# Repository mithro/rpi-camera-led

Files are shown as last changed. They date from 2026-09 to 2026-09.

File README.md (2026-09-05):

# RPi Camera LED

An interposer for the Raspberry Pi camera flex cable (15 pin, 1.0 mm pitch FPC).
It sits in the middle of the cable, passes all fifteen camera signals straight
through, and adds a CH32V003A4M6 that gives the Pi I2C-controlled camera GPIO,
PWM illumination LEDs and an ambient light reading.

## Hardware

[KiCad schematic](hardware/rpi-camera-led.kicad_sch) ·
[PDF](hardware/rpi-camera-led.pdf) ·
[board](hardware/rpi-camera-led.kicad_pcb)

### Board: 15-way FFC camera interposer

| 3D render, top | 3D render, bottom | Layout (copper, silk, outline) |
|:---:|:---:|:---:|
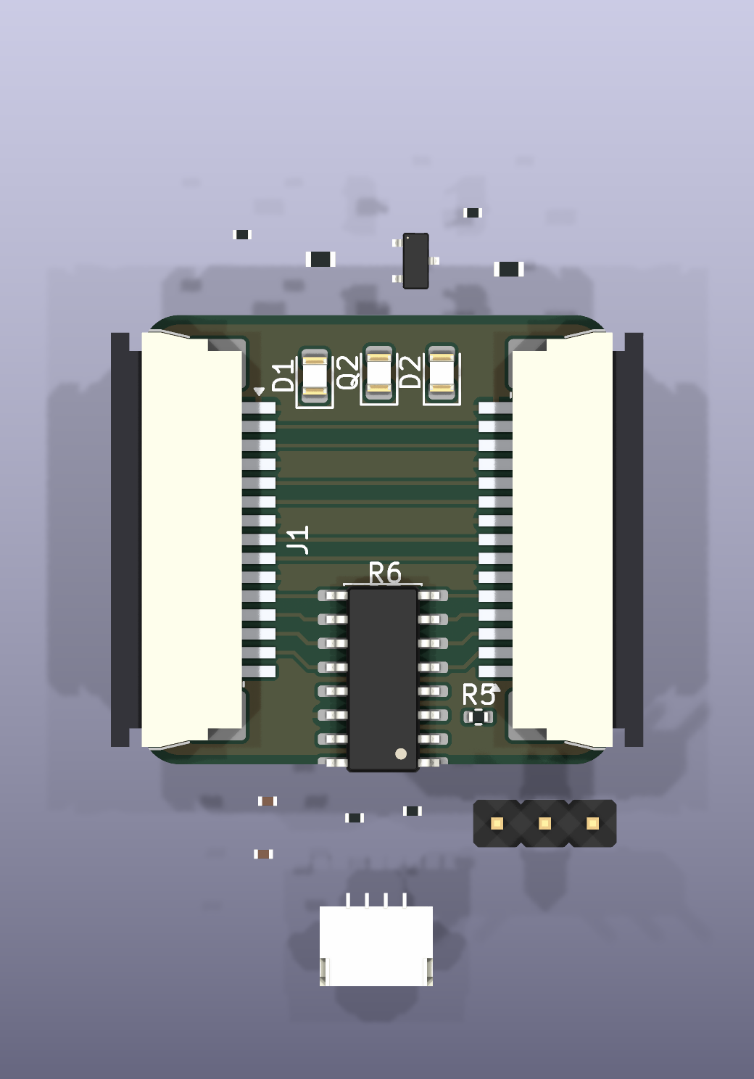
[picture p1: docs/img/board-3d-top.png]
Interposer, front side
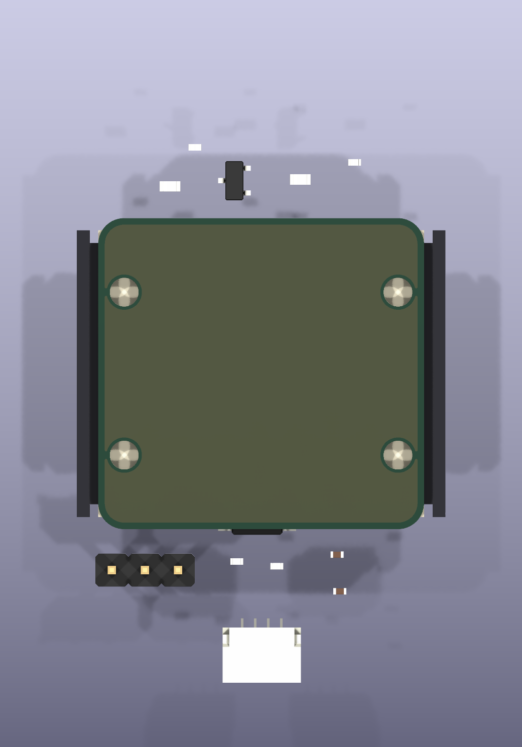
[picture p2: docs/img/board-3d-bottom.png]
Interposer, back side
|  |  | Interposer copper layout |

25.0 × 23.9 mm, two layers, everything on the front. J1 (left) faces the
Raspberry Pi and J2 (right) faces the camera; they sit 180° apart so the two
cable segments leave opposite edges and the board drops into an existing cable
run in line. The MCU is the SOIC-16 in the middle, the two white illumination
LEDs and the phototransistor are along the top edge.

The outline is the Camera Module 2 board: 25.000 × 23.862 mm with 2.0 mm corner
radii, and the same four Ø2.2 mm mounting holes, so the interposer takes the
camera's screws. Those come straight off the official mechanical drawing
([RP-008149-DS](https://pip.raspberrypi.com/categories/1205-drawings-and-schematics),
RPI-CAM-V2_1): *"4x 2.2mm diameter holes"*, 2 mm in from each end of the 25 mm
axis — a 21.0 mm pitch — and 12.5 mm apart on the other. `check_pcb.py` now
verifies pitch and drill, because these went missing once already without
anyone noticing.

**The layout is in progress.** Eleven of the twenty footprints — C1, C2, J3,
J4, Q1, R1–R4, R8 and R9 — are still parked outside the board outline, which is
why they float around the board in the renders. The fifteen-way pass-through
bus is routed; the rest is not. DRC reports 21 violations and 34 unconnected
items.

Four of those violations are the mounting holes, and they are a real conflict
rather than noise. **All four holes land underneath a connector housing.** On
the camera the 21.0 mm pitch runs between two edges that carry nothing, and its
single FFC connector sits on a third; this board has a connector on *both* ends
of that axis, each housing 5.30 mm deep, so the holes — 2 mm in from each end —
sit under them. Nothing on the board is wrong in isolation; the camera's
mounting pattern and two edge-mounted connectors simply cannot both fit on a
25 mm span. Resolving it means giving something up: a longer board, connectors
on the 25 mm edges instead, or mounting holes that no longer match the camera.

### How the cables run

| With cables fitted | Isometric |
|:---:|:---:|
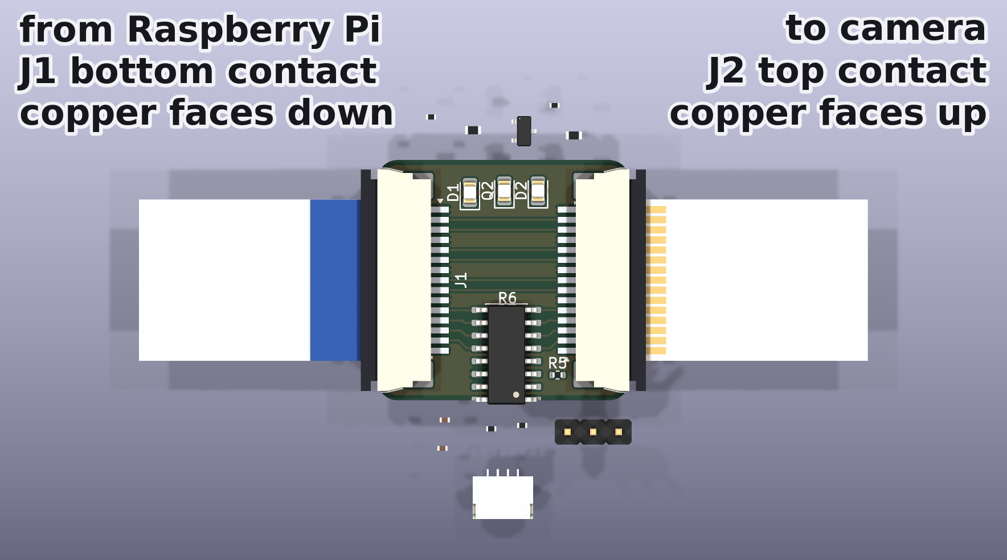
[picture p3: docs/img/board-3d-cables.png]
Interposer with FFC cables in both connectors
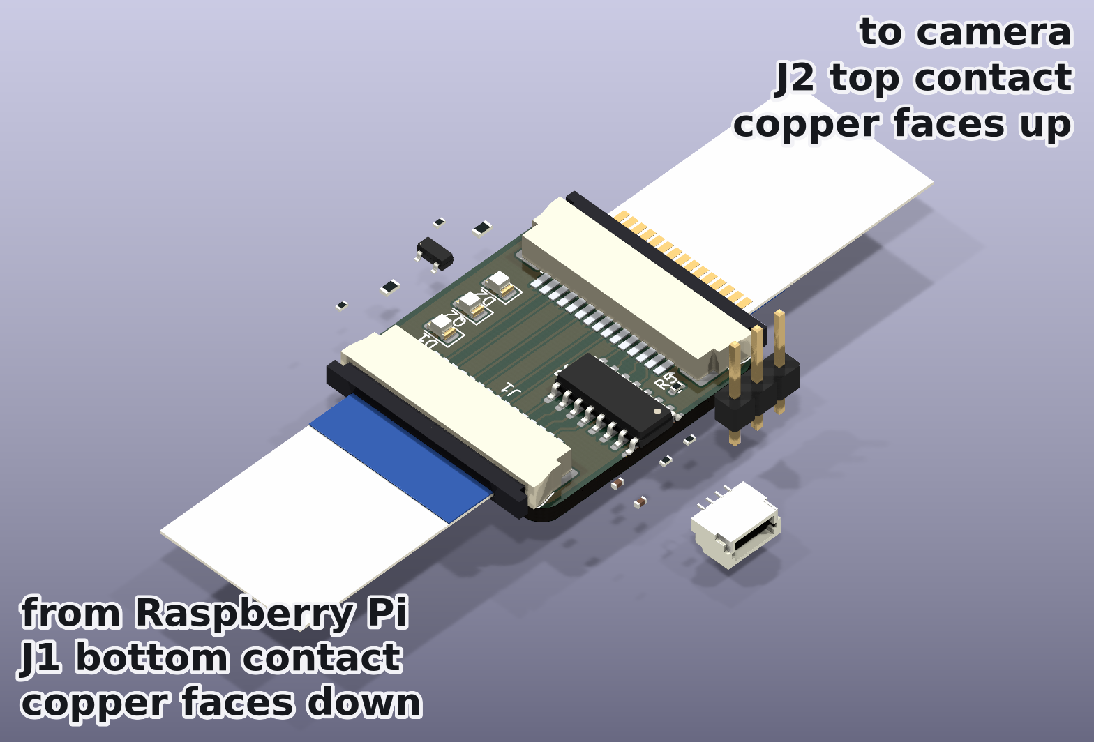
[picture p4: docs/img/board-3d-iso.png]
Isometric view of the interposer with cables
|  |  |

Both cables enter from the **outside** edges and run away from the board in
opposite directions, so the interposer drops into an existing cable run in
line. That follows from where the cable entry is on this connector: the
manufacturer's Section A‑A shows the solder tail stepping down and out at one
end while the cable channel opens at the other, and the top view labels
*Terminal* at one end and *Latch* at the other with the 5.30 mm housing
between them. It is also the only way a slide lock can work — you pull the
slider, insert the cable and push it back, all at the same end. So the cable
entry is at the latch end, away from the pads, and with each connector's
housing flush against its board edge that entry points outward.

The two cable stubs are drawn different ways up, and that is the point. J1 is
bottom contact, so its cable presents bared copper *downwards* and shows you
the blue backing; J2 is top contact, so its cable is the other way up and
shows you the conductors. That flip is the whole reason for pairing an F part
with an E part, and it is what lets both segments be ordinary Raspberry Pi
camera cables — the same flip you can see in a real cable, blue stiffener on
one face at one end, bared conductors on the other face at the other.

The stubs are illustrative and are not part of the board: they exist only in a
throwaway copy that the render script builds and deletes. Their 16.00 × 0.30 mm
section is the drawing's recommended FFC dimension. The bared conductors and
the backing are drawn a little longer than the 4 mm insertion depth so that a
few millimetres of each stay visible outside the connector — otherwise the
orientation they exist to show would be buried inside it.

Regenerate the images with `uv run hardware/tools/render_board.py`, and the
connector models with `uv run hardware/tools/gen_connector_model.py`. The
render script refills the copper zones first, via the pcbnew Python module
inside the KiCad snap, because `kicad-cli` has no zone-fill command and a
stale pour renders as authoritatively as a fresh one — when this was first
wired up the stored B.Cu pour was less than half its true area, and refilling
it dropped DRC from 116 violations to 17.

### Connectors, and which cables fit

J1 and J2 are **not** the same part, and that is deliberate:

| | part | contacts | mates with |
|---|---|---|---|
| **J1** → Raspberry Pi | JUSHUO AFA07-S15**F**CA-00 (LCSC C262721) | **bottom** — cable copper faces the board | a standard Pi camera cable |
| **J2** → camera | JUSHUO AFA07-S15**E**CA-00 (LCSC C262742) | **top** — cable copper faces away | a standard Pi camera cable |

The reason is cable parity. A Raspberry Pi camera cable is an *opposite-side*
FFC — "type 2", contacts on one face at one end and the other face at the other
— because the Pi's CSI socket is top-contact and the camera module's is
bottom-contact. Cutting one continuous cable anywhere yields one same-side half
and one opposite-side half, so an interposer whose two connectors want the
copper on the *same* face forces one odd, hard-to-buy cable. One that wants it
on *opposite* faces absorbs the asymmetry, and both segments become ordinary
Raspberry Pi camera cables. Bottom-contact at J1 plus top-contact at J2 is that
pairing.

The two variants share one land pattern — verified against both JUSHUO drawings
— so nothing on the board moves between them. Since only the contact side
differs, and it is invisible on an assembled board, the distinction is called
out in each symbol's value, in the MPN, and as a `BOTTOM CONTACT` / `TOP
CONTACT` marker on the fab layer.

Both footprints and their 3D models live in this repository, in
`hardware/rpi-camera-led.pretty` and `hardware/rpi-camera-led.3dshapes`. KiCad's
stock footprint references a STEP file for the JUSHUO AFA07 series that does not
exist — not in the KiCad distribution and not in `kicad-packages3D` upstream,
which ships no JUSHUO models at all. Third-party libraries have one, but under
terms that forbid redistribution, so `hardware/tools/gen_connector_model.py`
builds it from the manufacturer's published drawing instead: a 22.00 × 6.95 ×
2.50 mm envelope matching the drawing's DIM D, the F.Fab outline and the side
view's height, with the housing and latch coloured as the drawing's notes
specify. Both STEP and WRL are generated, the latter in the 0.1-inch units
KiCad expects.

The pass-through bus is wired J1 pin *k* ↔ J2 pin *16−k*. That looks reversed
but is exactly right: the two connectors are 180° apart, so J1 pad *k*
physically faces J2 pad *16−k*, and joining the pads that face each other is
both the straight route and the electrically transparent one — the board
behaves as a splice in the middle of one continuous cable.
`check_pcb.py` measures that facing alignment as a number, because losing it to
a stray drag puts a dogleg in all fifteen nets and is invisible by eye.

### Verifying

```
uv run hardware/tools/check_schematic.py   # ERC + netlist vs design intent
uv run hardware/tools/check_pcb.py         # connector alignment + DRC parity
```

`check_schematic.py` currently **fails**: its expected-netlist table still
describes the older pin-for-pin bus, and four issues from the last eeschema
session are open — U1 pin 13 is unconnected, SWIO and CAM_IO1 have been merged
onto one net, I2C is landed on pins that cannot carry it on this package (the
CH32V003 SOP-16 reaches the peripheral only on pins 1 and 2, since both AFIO
remaps need PD0 or PC5 and the package bonds out neither), and four no-connect
flags dangle.

The schematic is maintained by hand in eeschema — connections between adjacent
parts are drawn as wires rather than left implicit in matching global labels.
`hardware/tools/gen_schematic.py` is the generator that bootstrapped it, but
**running it overwrites the schematic** and would discard that manual wiring.

## Firmware

[CH32V003 firmware](firmware/README.md): a fail-safe I2C bootloader plus an
application exposing camera GPIO control, RPi-side GPIO readback, GPIO
pass-through, LED brightness (hardware PWM) and an ambient light reading over
a Linux-friendly SMBus register map at address 0x42. Builds with
`riscv64-unknown-elf-gcc` and [ch32v003fun](https://github.com/cnlohr/ch32v003fun)
(`git submodule update --init`, then `make` in `firmware/bootloader` and
`firmware/app`).

The firmware still targets the older pin map and needs updating to match the
current schematic.

## Research

Part availability research comparing [JLCPCB's PCBA parts
library](https://jlcpcb.com/parts) and [NextPCB's Rev0
service](https://www.nextpcb.com/rev0-pcba) (which sources components from [HQ
Online](https://www.hqonline.com/)'s 600k+ in-stock inventory):

* [I2C controllable RGB LEDs](research/i2c-rgb-leds.md)
* [I2C GPIO expanders with LED driving capability](research/i2c-gpio-expanders.md)
* [Cheap (< $0.50) MCUs with I2C and no external parts required](research/cheap-mcus.md)
* [RPi camera compatible FPC connectors (1.0 mm pitch, 15 pin)](research/fpc-connectors.md)

## License

Apache 2.0 — see [LICENSE](LICENSE).

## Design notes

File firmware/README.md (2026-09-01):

# CH32V003J4M6 camera-LED controller firmware

Firmware for the CH32V003J4M6 (RISC-V, SOP-8) sitting on the Raspberry
Pi camera interposer board in this repository. It:

1. drives or tri-states the two camera-side GPIO pins,
2. reads back the two Pi-side GPIO pins (via the tri-stated passthrough),
3. can put either channel into "copy mode" (the Pi's GPIO passes
   straight through to the camera),
4. continuously samples and averages an ambient-light phototransistor,
5. drives two white illumination LEDs via hardware PWM, and
6. supports a fail-safe firmware upgrade over I2C.

Everything is controlled by a Raspberry Pi over I2C, using a plain
"8-bit register pointer, auto-incrementing" protocol compatible with
`i2c-tools` (`i2cget`/`i2cset`/`i2ctransfer`) and kernel `regmap-i2c`
drivers out of the box.

**Build status: builds clean with fully open-source tooling (see
"Build" below). Hardware status: UNTESTED. Nobody has flashed this
onto a real board or scoped a single pin -- see "Known risks" and
"What is untested" at the end of this document.**

## Hardware

(As specified by the person who wrote this brief, verified against the
WCH datasheet.) The chip is a CH32V003J4M6 in an SOP-8 package. Several
package pins are bonded to two GPIO ports simultaneously inside the
package, which the firmware must account for:

| Package pin | Port(s) | Net | Notes |
|---|---|---|---|
| 1 | PD6 **and** PA1  | CAM_IO0 | Drives camera GPIO 11. Also wired through a 10k (R6) to the Pi's CAM_IO0: when the CH32 pin is an input, the Pi's state passes through to the camera and is readable by the CH32; when the CH32 drives it, it overrides the Pi (0.33mA through the 10k). |
| 3 | PA2 | CAM_IO1 | Same scheme via R7 (10k) to the Pi's CAM_IO1. |
| 5 | PC1 | I2C1_SDA  | CH32 is an I2C **slave** on the Pi camera bus (100-400kHz), shared with the camera sensor (0x10/0x1A/0x36) and EEPROMs (0x50/0x54). |
| 6 | PC2 | I2C1_SCL  | |
| 7 | PC4 | ADC A2 | Phototransistor, 47k to GND; more light = higher voltage. |
| 8 | PD1, PD4, PD5 | LED gate  | PD1 drives an N-MOSFET gate (100R series, 10k pulldown) switching two white LEDs, via TIM1 channel 3 complementary output (T1CH3N). PD1/SWIO is also the programming pin -- LEDs flicker during flashing, by design. |

Because pins 1 and 8 are bonded to more than one port, the firmware
configures the *unused* half of each bonded pin as a floating input
for its entire lifetime, so it never fights the pin it's bonded to:
PA1 (pin 1) and PD4/PD5 (pin 8) are always `GPIO_CFGLR_IN_FLOAT`. This
is also the chip's power-on-reset default for every GPIO, so the
bootloader (which never touches these pins) is safe by construction,
and the app explicitly re-asserts it at startup as a defensive measure
(`app/app.c`, `main()`).

I2C slave address: **0x42** (`I2C_SLAVE_ADDR` in `common/layout.h`),
chosen to avoid the camera (0x10/0x1A/0x36) and EEPROMs (0x50/0x54)
already on the bus.

## Architecture

16KiB of flash is split into two independently-linked images:

```
0x0000 - 0x0FFF   bootloader   (4KiB)   -- always runs first
0x1000 - 0x3FFF   application  (12KiB)  -- code + a 16-byte trailer
```

2KiB of SRAM is shared: the first 16 bytes are reserved for a
cross-reset handshake word (see "Upgrade protocol" below) that is
**not** zeroed by C runtime startup, so it can carry a value across a
warm reset; the rest is split identically by both linker scripts
(`bootloader/bootloader.ld`, `app/app.ld`) but is otherwise fully
available to whichever image is currently running -- the two images
are never active at the same time, so there's no need to partition RAM
between them beyond that one shared word.

The bootloader **always** runs first (the chip always starts executing
at flash address 0 after reset). On every boot it:

1. Computes the application's CRC32 and compares it to the CRC32
   stored in the application's own trailer.
2. If valid **and** no upgrade was requested, jumps straight to the
   application. This is not free: the CRC32 is bit-banged (see
   `common/crc32.h`, deliberately table-free to save flash) at roughly
   70 CPU cycles per byte, so 12KiB costs on the order of **20ms** at
   48MHz. The device does not acknowledge anything on I2C during that
   window, on every reset and every power-on. That is comfortably
   inside the time a Raspberry Pi takes to get as far as probing the
   camera bus, but it is worth knowing about, and it is the price of
   the guarantee in point 1.
3. Otherwise, stays resident and serves the I2C bootloader protocol
   until a host either fixes the app and asks it to run, or the app
   itself explicitly asks to be interrupted for an upgrade.

The bootloader **never** erases or programs any flash address outside
the 12KiB application region -- see `program_page()` in
`bootloader/bootloader.c`, which bounds-checks every page index
against `APP_NUM_PAGES` before touching the flash controller. There is
no code path, valid or malformed I2C command, that can make it write
to its own 4KiB.

### Why two separately-linked images "just work"

Each image is built by ch32fun's normal startup code (`handle_reset`
in the submodule's `ch32fun.c`), which sets `mtvec` to that image's
*own* `InterruptVector` symbol (`la a3, InterruptVector; ori a3,a3,3;
csrw mtvec,a3`) and jumps into that image's own `main()`. Since the
bootloader and app are linked with different `FLASH` origins
(`bootloader.ld`: `0x00000000`; `app.ld`: `0x00001000`), this happens
automatically -- the bootloader does not need to (and does not)
manually relocate the app's vector table. "Jumping to the app" is
therefore just a plain function-pointer call to `APP_FLASH_BASE`
(`0x00001000`), which lands on the app's own reset vector and the app
takes it from there (`jump_to_app()` in `bootloader.c`).

Flash reads/writes/erases use the *physical* address
(`APP_FLASH_PHYS_BASE = 0x08001000`), matching how
`ch32v003fun/examples/flashtest/flashtest.c` uses the flash controller
-- the CPU's normal code-fetch/read path uses the *aliased* address
(`APP_FLASH_BASE = 0x00001000`, the boot-remapped alias flash sits at
after reset) for execution. Both addresses read the same bytes; only
the *jump* target needs to be the aliased one (to match what `mtvec`/
`la` compute), and only the flash-controller `FLASH->ADDR`/buffer
writes need to be the physical one (as demonstrated by the stock
`flashtest.c` example).

## Register map (application mode)

I2C slave address `0x42`. All registers are 8-bit-addressed with
auto-increment (a write's first byte sets the pointer; further bytes
in the same write auto-increment it; a read serves from the pointer
and also auto-increments) -- see `common/i2c_slave.h` (MIT-licensed,
vendored from the ch32v003fun submodule's `examples/i2c_slave` **with
local bug fixes**, listed in the header comment of that file). This is
the same "dumb register file" shape `i2c-tools` and kernel
`regmap-i2c` drivers expect.

Both a combined write-then-read (repeated START -- what `regmap-i2c`,
`i2cget -c` and the `I2C_RDWR` ioctl issue) and a separate
write-then-STOP-then-read work: the register pointer is remembered
across transactions, and each addressing phase restarts the burst from
it. The pointer is *not* advanced by a completed read, so repeating a
read without rewriting the pointer re-reads the same registers.

Registers marked RO are re-stamped by the firmware from private state.
The underlying slave driver has one read-only flag for the entire
register file, and the file has to be writable for the RW registers,
so a host physically *can* write to an RO offset -- but the firmware
never believes what it finds there and restores it.

| Reg  | Name | R/W | Description |
|---|---|-----|---|
| 0x00 | WHO_AM_I | RO  | `0xC3` in application mode, `0xB1` in bootloader mode -- read this first to know which one you're talking to. |
| 0x01 | FW_VERSION | RO  | Application firmware version (currently 1). |
| 0x02 | CTRL | RW  | bit0/bit1 = copy-mode enable, channel 0/1. |
| 0x03 | GPIO_OUT | RW  | bit0/bit1 = driven output level, channel 0/1 (only takes effect if OE=1 and copy-mode is off for that channel). |
| 0x04 | GPIO_OE | RW  | bit0/bit1 = 1: drive the pin per GPIO_OUT, 0: tri-state (input). Ignored (forced to tri-state) while copy-mode is enabled for that channel. |
| 0x05 | GPIO_IN | RO  | bit0/bit1 = live pin level, channel 0/1. When tri-stated (copy mode, or OE=0) this is the Pi's passed-through state; when driven (OE=1, copy mode off) this reads back the value we're driving. |
| 0x06 | LED | RW  | LED brightness, 0-255, hardware PWM (~1kHz). 0 is fully off (0% duty), 255 is fully on (100%, not 255/256). |
| 0x07 | (reserved) | - | Reads as 0. |
| 0x08-0x09 | LIGHT | RO  | Illumination, little-endian 16-bit, exponentially averaged (8-sample time constant at 100Hz sampling). Raw ADC is 10-bit, so the value ranges 0-1023, not the full 16-bit range. The two bytes are updated with interrupts masked, so a single 2-byte burst read always returns one consistent sample. |
| 0x7F | BOOT | WO  | Write `0xB0` to ask the running app to reset into the bootloader for a firmware upgrade. |

**Copy mode precedence:** if `CTRL` bit *n* is set, channel *n* is
**always** tri-stated regardless of `GPIO_OE` bit *n* -- that tri-state
*is* the passthrough (the Pi's own driver, through the 10k resistor,
is what reaches the camera; the CH32 just gets out of the way and
reports what it reads back on `GPIO_IN`).

## Register map (bootloader mode)

Same I2C address (`0x42`) and same register-pointer/auto-increment
protocol, exposed only while the bootloader is resident. `WHO_AM_I`
reads `0xB1` here (vs `0xC3` in app mode) so a host can always tell
which firmware it's talking to just by reading register 0.

| Reg | Name | R/W | Description |
|---|---|-----|---|
| 0x00 | WHO_AM_I | RO  | `0xB1`. |
| 0x01 | BL_VERSION | RO  | Bootloader version (currently 1). |
| 0x02 | STATUS | RO  | bit0 BUSY, bit1 OK (last op), bit2 ERR (last op), bit3 APP_VALID (result of the most recent CRC32 check). Informational only -- `RUN_APP` re-verifies from flash and does **not** consult this bit. |
| 0x03 | CMD | WO  | Write a command byte: `0x01` PROGRAM_PAGE, `0x02` VERIFY_APP, `0x03` RUN_APP. BUSY is raised in the same interrupt that accepts the write, so a host may poll STATUS immediately afterwards without racing the command's start. |
| 0x04 | PAGE_INDEX | RW  | Page number (0-191) within the 12KiB application region, for the next PROGRAM_PAGE. |
| 0x05-0x06 | PAGE_CSUM | RW  | Little-endian CRC16/CCITT-FALSE of the 64-byte PAGE_BUF, checked by the bootloader before it touches flash. |
| 0x07 | (reserved) | - | Reads as 0. |
| 0x08-0x47 | PAGE_BUF | RW  | 64-byte page data buffer (the CH32V003's flash erase granularity). |
| 0x48-0x4B | APP_CRC32 | RO  | Little-endian, the CRC32 computed by the most recent VERIFY_APP (or the automatic check at bootloader entry). |
| 0x4C-0x4F | APP_SIZE | RO  | Little-endian, `app_header_t.app_used_size` as last read from flash (always 12288 for images built by this repo's tooling). |

### `PROGRAM_PAGE` semantics

Writing `0x01` to `CMD` erases, programs, and read-back-verifies
*exactly one* 64-byte page of the application region at `PAGE_INDEX`,
from `PAGE_BUF`, but **only if** the CRC16 the bootloader computes over
`PAGE_BUF` matches `PAGE_CSUM` -- a mismatch aborts before touching
flash and sets the ERR bit. This work happens in the bootloader's main
loop (not the I2C interrupt handler), so it can take a few
milliseconds (flash page erase is documented elsewhere in the
ch32v003fun project as ~3ms); **a host must poll STATUS until BUSY
clears (or simply wait ~10ms) before sending the next command** --
see `_wait_not_busy()` / `_program_page()` in `host/rpi_camera_led.py`.
`PAGE_INDEX` is always bounds-checked against the 192-page application
region before any flash access, so a confused or malicious host cannot
make the bootloader touch its own 4KiB.

## Upgrade protocol and its fail-safety argument

The application's flash image ends in a 16-byte trailer
(`app_header_t`, `common/app_header.h`) occupying exactly the last 16
bytes of the last (192nd) page of the application region:

```c
typedef struct {
    uint32_t magic;          // must equal 0xCAFEB007
    uint32_t app_used_size;  // bytes covered by crc32 below, from the
                              // start of the app region (always 12288
                              // for images this repo's tooling builds)
    uint32_t app_crc32;      // CRC32 (zlib/CRC-32/ISO-HDLC variant) of
                              // app_used_size bytes, computed with THIS
                              // FIELD treated as zero
    uint32_t reserved;       // must be 0
} app_header_t;
```

Because the trailer sits at a fixed, compile-time-known address
(`APP_HEADER_ADDR = 0x00003FF0`) regardless of how big the actual
compiled code is, the bootloader never needs to trust anything about
the application's own build beyond this one fixed struct.

The full upgrade sequence, driven by `host/rpi_camera_led.py upgrade`:

1. If the device is currently running the app, write `0xB0` to
   `REG_BOOT`. The app stashes a magic value in the shared NOINIT RAM
   word and triggers a full system reset (`PFIC->SCTLR = 1<<31`). The
   bootloader (which always runs first) sees the magic value, clears
   it, and stays resident regardless of whether the current app's CRC32
   is valid.
2. For each of the 192 pages: write `PAGE_INDEX`/`PAGE_CSUM`/`PAGE_BUF`
   in one I2C transaction, then write `CMD = PROGRAM_PAGE` in a second,
   then poll `STATUS` until not-BUSY and check OK.
3. Write `CMD = VERIFY_APP`; poll; check `APP_VALID`.
4. Write `CMD = RUN_APP`; the bootloader jumps to the (now verified)
   app.

**Why a power cut at any point in this sequence is recoverable:**

- *Before any page is written*, the flash is whatever it was before --
  either the previous (working) app, or already-invalid flash from an
  earlier interrupted attempt. Either way, the CRC32 check at the next
  boot reflects reality.
- *During any single page's erase+program*, the flash controller
  (per `ch32v003fun/examples/flashtest`) can leave that specific page
  in an indeterminate state (partially erased, partially programmed)
  if power is cut mid-operation. This is **not** made atomic by this
  firmware -- it can't be, on this hardware, without a second flash
  bank to hold a journal, which a 16KiB part doesn't have. What *is*
  guaranteed is that the CRC32 check covers the **entire** 12KiB
  region, so **any** single corrupted page (this one, or the one
  holding the header trailer itself) makes the whole-image CRC32
  mismatch on the next boot, and the bootloader falls back to staying
  resident rather than running a partially-written image. The
  in-progress page write is bounds-checked to the app region the whole
  time, so even a power cut mid-erase can never touch the bootloader's
  own 4KiB.
- *Between pages*, or *after the last page but before VERIFY_APP/
  RUN_APP*, the trailer's CRC32 still describes whatever combination of
  old and new page contents happens to be in flash at that instant,
  which (overwhelmingly likely) does not match -- same fallback.
- *A power cut during RUN_APP itself* just means the reset happens
  before the jump instead of after; the bootloader re-runs its CRC32
  check from scratch on the next boot regardless.

There is also **no I2C command sequence that can make the bootloader
jump into an unverified image**. `RUN_APP` recomputes the CRC32 from
flash at the moment of the jump and ignores `BREG_STATUS`; the status
register is host-writable (see the note under "Register map
(application mode)"), so gating the jump on its `APP_VALID` bit would
have let a host write `[0x02, 0x08, 0x03]` -- STATUS = APP_VALID
followed by CMD = RUN_APP in one transaction -- and jump into a blank
or half-programmed app region. Likewise `app_used_size` read out of
the flash trailer is required to be exactly `APP_SIZE` before it is
used as a CRC length, because a corrupt smaller value would underflow
the length arithmetic into a multi-gigabyte walk past the end of flash
and hang the bootloader on every boot.

In short: **the fail-safety guarantee rests entirely on the CRC32
check being cheap, unconditional, and run on every single boot (and
again immediately before every jump) before anything else** -- not on
any single I2C transaction being atomic. The
cross-reset NOINIT handshake word (step 1 above) is *not* part of this
guarantee; it only affects whether the bootloader stays resident when
the CRC32 *is* valid (letting an intentional re-upgrade interrupt a
working app). Concretely: SRAM content after a genuine cold power-on
is not architecturally guaranteed to be any particular value, so this
firmware never relies on the handshake word being zero/absent after a
real power loss -- it only ever matters when the CRC32 is already
valid, and reading it as (spuriously) "enter bootloader" in that case
just means an extra unnecessary stay-in-bootloader, never an unsafe
boot into a bad image.

**What this cannot rule out, honestly:** CRC32 is not a cryptographic
checksum. A pathological, exactly-crafted flash corruption pattern
could in principle produce a wrong image whose CRC32 happens to match
its own (also corrupted) stored CRC32 field. Against the kind of
corruption that a power loss during a page erase/program actually
produces (a page left all-0xFF, all-0x00, or a mix of old/new 32-bit
words), this is not a realistic failure mode, but it is not
mathematically impossible, and this document says so plainly rather
than overclaiming.

The I2C-transport-level `PAGE_CSUM` (CRC16) is a **separate**, weaker
check that only protects a single page transfer against I2C bus
corruption *before* it reaches flash -- it plays no role in the
boot-time safety argument above, which is CRC32-only.

## Build

Requires `riscv64-unknown-elf-gcc` (Debian/Ubuntu package
`gcc-riscv64-unknown-elf`) and `uv` (for the trailer-patching Python
step). Both bootloader and app are built with
`-march=rv32ec -mabi=ilp32e`, matching what `ch32v003fun`'s own
`ch32fun.mk` selects for `TARGET_MCU=CH32V003`.

```sh
git submodule update --init firmware/ch32v003fun   # if not already checked out
cd firmware/bootloader && make build
cd ../app && make build
```

Each `Makefile` enforces its flash budget at build time (`checksize`
target) in addition to the linker's own `--print-memory-usage` report,
using `objcopy -O ihex`/`-O binary` for the standard `.elf`/`.bin`/
`.hex` outputs.

Measured sizes (this repository, current sources, gcc 14.2.0):

```
Bootloader:  2248 / 4096  bytes flash (54.9%),  144 / 2032 bytes RAM
App:         2020 / 12272 bytes flash (16.5%),  184 / 2032 bytes RAM
```

(App flash budget is 12272, not 12288 -- the linker script reserves
the last 16 bytes for the trailer that `app/make_trailer.py` patches
in after linking, so the *build itself* fails loudly if application
code would collide with the trailer, rather than silently producing a
corrupt image.)

## Flashing

This firmware has not been flashed to real hardware (see "What is
untested" below). `make flash` in either `bootloader/` or `app/` uses
`minichlink` (built from the `ch32v003fun` submodule, also fully
open-source) over a WCH-LinkE-compatible SWD programmer connected to
the shared SWIO/PD1 pin. Because PD1 is also the LED PWM pin, the LEDs
will flicker while flashing the app image -- this is expected and
harmless.

```sh
cd firmware/bootloader && make flash   # minichlink -w bootloader.bin flash        (0x08000000)
cd firmware/app        && make flash   # minichlink -w app.bin        flash+0x1000 (0x08001000)
```

**Do not use ch32fun.mk's own `cv_flash` target for the application.**
Its `FLASH_COMMAND` writes the image to the bare `flash` address, i.e.
the *start* of flash, which for this image would drop 12KiB of
application (linked to run at 0x1000) on top of the 4KiB bootloader.
`app/Makefile` therefore defines its own `flash` target at
`flash+0x1000`; it also depends on `build` rather than just `app.bin`,
so it cannot flash an image whose `app_header_t` trailer has not been
patched in yet.

The bootloader only needs to be flashed once (via SWD); subsequent
application updates go over I2C via `host/rpi_camera_led.py upgrade`,
which never touches the bootloader's own flash region.

## Host tool

`host/rpi_camera_led.py` (run with `uv run rpi_camera_led.py ...`,
stdlib-only, no packages to install) talks to `/dev/i2c-N` via a small
ctypes wrapper (`host/i2c_raw.py`) around the same `I2C_RDWR` ioctl
`i2c-tools`/`smbus2` use, so it does not depend on `smbus2` at all.

```sh
uv run host/rpi_camera_led.py --bus 1 status
uv run host/rpi_camera_led.py --bus 1 set-led 128
uv run host/rpi_camera_led.py --bus 1 set-oe 0 1
uv run host/rpi_camera_led.py --bus 1 set-gpio 0 1
uv run host/rpi_camera_led.py --bus 1 set-copy 1 1
uv run host/rpi_camera_led.py --bus 1 get-light
uv run host/rpi_camera_led.py --bus 1 upgrade firmware/app/app.bin
```

`upgrade` accepts either a raw linked `app.bin` (it builds and patches
the trailer itself, using `host/app_trailer.py`) or an already-
trailered 12288-byte image (it verifies the trailer before flashing
rather than trusting it blindly).

## Known risks

Things that are *probably* wrong, or that are known to be delicate, but
that cannot be resolved without a board on a bench. Each one says what
to try first if bring-up goes badly, so nobody has to rediscover them.

1. **`I2C1->CTLR2.FREQ` is very likely programmed with the wrong
   value.** `SetupI2CSlave()` computes it as
   `FUNCONF_SYSTEM_CORE_CLOCK / 2000000` = **24**, treating it as a
   divider. The reference manual defines `FREQ[5:0]` as the APB1 clock
   expressed **in MHz**, which here is **48**. FREQ does not set the
   bit rate (that is `CKCFGR`, and only in master mode), but it does
   set the peripheral's internal setup/hold and spike-filter timing, so
   understating it by 2x could violate SDA hold time -- most likely to
   show up at 400kHz, least likely at 100kHz. This has deliberately
   **not** been changed: both places in `ch32v003fun` that touch this
   field (`examples/i2c_slave/i2c_slave.h`, which this file is vendored
   from, and `extralibs/ssd1306_i2c.h`, a widely-used working I2C
   master) use the same expression, so changing it on paper alone
   would be trading a field-proven value for a manual-correct one with
   nothing to test either against. **If the slave misbehaves on a real
   bus, try `FREQ = FUNCONF_SYSTEM_CORE_CLOCK / 1000000` first.**

2. **Clock stretching versus the Raspberry Pi's I2C master.** The
   CH32V003 I2C slave holds SCL low until its event interrupt services
   ADDR/RxNE/TxE. The Pi's `i2c-bcm2835` controller has documented
   trouble with slaves that stretch the clock (the BCM2835 datasheet
   erratum around stretching at the start of a read). Because the
   camera bus is shared with the sensor and the EEPROMs, a badly-timed
   stretch could disturb them too. If this bites, the mitigations are
   to run the bus at 100kHz and to keep the app's interrupt latency
   low; there is no firmware-side way to avoid stretching entirely on
   this peripheral.

3. **The slave stops responding for ~3ms per programmed page.** A
   64-byte erase+program stalls the CPU (that is ch32v003fun's own
   measured figure in `examples/flashtest`), so the I2C event ISR
   cannot run and the master sees the slave stop acknowledging.
   `host/rpi_camera_led.py` waits 10ms after writing `CMD` before it
   starts polling `STATUS`, but whether the Pi's kernel driver reports
   a clean timeout the tool can retry, or something worse, is untested.
   If it turns out to need retries, add them around `_wait_not_busy()`
   in the host tool rather than changing the firmware.

4. **Interrupts are left enabled across flash erase/program.** The I2C
   event ISR executes out of the bootloader's own flash pages while the
   flash controller is busy with a page in the app region.
   ch32v003fun's `flashtest` example already depends on code executing
   from flash during a program (its busy-wait loop is fetched from
   flash), so this is believed safe, but it has not been verified with
   an interrupt firing mid-operation. If page programming proves
   unreliable, wrap `program_page()` in `__disable_irq()` /
   `__enable_irq()` -- at the cost of holding SCL low for the duration.

5. **ADCCLK is 24MHz (HCLK/2).** Copied from ch32v003fun's
   `adc_polled` and `adc_fixed_fs` examples, which both call that the
   right setting for this part -- but ch32fun's own `funAnalogInit()`
   carries an STM32-derived comment saying the ADC clock should not
   exceed 14MHz. The longest sample time (241 cycles, ~10us at 24MHz)
   leaves the 47k phototransistor load plenty of settling time either
   way. If readings look noisy or nonlinear, drop `ADCPRE` to /4 or /8;
   at 100Hz sampling there is no time pressure at all.

6. **Slave-transmitter NAK handling is inherited, not verified.** When
   a master NAKs the last byte of a read, the CH32 I2C leaves a byte
   loaded in `DATAR` and raises AF. The driver clears AF in the error
   handler and relies on the next ADDR event resetting `position` and
   the next TxE overwriting `DATAR`. That is how the upstream example
   behaves; it has not been scoped.

7. **A CRC-valid but functionally broken app is only recoverable over
   SWD.** The bootloader's only test is the CRC32; if an image checksums
   correctly but hangs, or never brings up its I2C slave, or never
   implements `REG_BOOT`, then the bootloader will hand control to it on
   every boot and nothing on the I2C bus can take it back. There is no
   dwell window in which the bootloader listens before jumping (adding
   one would mean answering at 0x42 during the camera bus's own probe
   on every power-up, which is its own hazard). The practical
   consequence: **only ever ship an app image that has been tested via
   `upgrade` on a board you can still reach with a WCH-LinkE**, and keep
   `REG_BOOT` working in every future app revision.

8. **CRC32 is not a cryptographic checksum**, so a pathological flash
   corruption pattern could in principle produce a wrong image whose
   CRC32 matches its own (also corrupted) stored value. See the
   discussion at the end of "Upgrade protocol" -- this is not a
   realistic outcome of a power cut during a page erase/program, but it
   is not mathematically impossible either.

## What is untested

**Nothing in this firmware has been run on real CH32V003J4M6 silicon,
or on any hardware at all.** Specifically untested:

- Whether the pin/peripheral configuration (GPIO alternate functions,
  ADC channel mapping, TIM1 NOREMAP CH3N routing to PD1) actually
  produces the described electrical behaviour on this specific
  package/board.
- Actual I2C bus timing and electrical behaviour of any kind -- see
  "Known risks" items 1-3 above, which cover the peripheral clock
  configuration, clock stretching against the Pi's master, and the
  slave going quiet during flash programming.
- The actual flash page-erase/program timing and read-back-verify
  behaviour on this specific chip revision, and whether relocking
  LOCK|FLOCK between pages (as `flash_lock()` now does) is required,
  merely harmless, or -- least likely -- itself a problem.
- Whether triggering `PFIC->SCTLR = 1<<31` from application code
  (used for the "enter bootloader" request) behaves as expected on
  this chip/silicon revision, and how long the I2C bus is unresponsive
  across that reset.
- The host tool's ioctl-based I2C implementation (`host/i2c_raw.py`)
  against a real Linux `i2c-dev` device node -- it has only been
  exercised against a Python-level mock of the bootloader's register
  state machine (see the git history for `firmware/host/`), which
  validates the *protocol logic* (page sequencing, checksums, mode
  transitions) but says nothing about real I2C electrical/timing
  behaviour.
- Real-world ADC noise/averaging behaviour of the phototransistor
  circuit, and whether the 100Hz/8-sample exponential average (~80ms
  to settle) is a sensible time constant for the actual sensor.
- LED PWM frequency (~1kHz) for visible flicker or EMI concerns.

Anyone bringing this up on real hardware should start with `make flash`
of the bootloader alone, verify `status` reports `mode: bootloader`
(a factory-blank chip has no valid app), then flash a minimal app and
work up from there.

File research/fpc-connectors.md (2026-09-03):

# FPC connectors compatible with the RPi camera cable (1.0 mm pitch, 15 pin)

Availability on both [JLCPCB's PCBA parts library](https://jlcpcb.com/parts) and
[NextPCB's Rev0 service](https://www.nextpcb.com/rev0-pcba) (which sources
components from [HQ Online](https://www.hqonline.com/)'s in-stock inventory).

The standard Raspberry Pi camera cable is a 15-way, 1.0 mm pitch, 0.3 mm thick
FFC with stiffened ends and contacts exposed on one side only. Any 15-position
1.0 mm FFC/FPC connector accepting 0.3 mm cable works mechanically; **pick top-
vs bottom-contact to match which side of the cable faces your board**. The
connector family used on Raspberry Pi boards themselves is Amphenol's SFW15R.

Data collected 2026-09-01 with [`tools/partsearch.py`](tools/partsearch.py);
raw output in [`data/fpc-connectors.jsonl`](data/fpc-connectors.jsonl). Prices
are the **unit price at a quantity of 100** in USD (multiply by 100 for the
cost of 100 units).

## Available on both services

| Product ID | Manufacturer | JLCPCB unit @100 | NextPCB unit @100 | JLCPCB | NextPCB (HQ Online) | Manufacturer page | Datasheet |
|---|---|---|---|---|---|---|---|
| AFA07-S15FCA-00 (bottom contact, slide lock) | JUSHUO (JS) | $0.0940 (6,252 in stock) | $0.0876 (1,634 in stock) | [C262721](https://jlcpcb.com/partdetail/JUSHUO-AFA07_S15FCA00/C262721) | [AFA07-S15FCA-00](https://www.hqonline.com/product-detail/fpc---ffc-connectors-js-afa07-s15fca-00-2500245049) | [jushuo.com](http://www.jushuo.com/)¹ | [PDF (LCSC)](https://wmsc.lcsc.com/wmsc/upload/file/pdf/v2/lcsc/2304140030_JUSHUO-AFA07-S15FCA-00_C262721.pdf) |
| AFA07-S15ECA-00 (top contact, slide lock) | JUSHUO (JS) | $0.1055 (12,866 in stock) | $0.0985 (1,500 in stock) | [C262742](https://jlcpcb.com/partdetail/JUSHUO-AFA07_S15ECA00/C262742) | [AFA07-S15ECA-00](https://www.hqonline.com/product-detail/fpc---ffc-connectors-js-afa07-s15eca-00-2500245070)² | [jushuo.com](http://www.jushuo.com/)¹ | [PDF (LCSC)](https://wmsc.lcsc.com/wmsc/upload/file/pdf/v2/lcsc/2304140030_JUSHUO-AFA07-S15ECA-00_C262742.pdf) |
| 1.0K-FX-15PWB (bottom contact, slide lock) | HDGC | $0.0933 (**only 3 in stock**) | $0.1296 (**only 5 in stock**) | [C2914074](https://jlcpcb.com/partdetail/HDGC-1_0K_FX15PWB/C2914074) | [1.0K-FX-15PWB](https://www.hqonline.com/product-detail/fpc---ffc-connectors-hdgc-1-0k-fx-15pwb-2500406100) | [hdgc.cn](http://www.hdgc.cn/)¹ | [PDF (LCSC)](https://wmsc.lcsc.com/wmsc/upload/file/pdf/v2/lcsc/2111021330_HDGC-1-0K-FX-15PWB_C2914074.pdf) |
| FPC-1.0FX-15PWCR-H20 (bottom contact, flip lock) | XUNPU | $0.1510 (3,270 in stock) | $0.1339 (1,440 in stock) | [C19269358](https://jlcpcb.com/partdetail/XUNPU-FPC_1_0FX_15PWCRH20/C19269358) | [FPC-1.0FX-15PWCR-H20](https://www.hqonline.com/product-detail/fpc---ffc-connectors-xunpu-fpc-1-0fx-15pwcr-h20-2500437310) | —¹ | [PDF (LCSC)](https://wmsc.lcsc.com/wmsc/upload/file/pdf/v2/lcsc/2311211841_XUNPU-FPC-1-0FX-15PWCR-H20_C19269358.pdf) |
| SFW15R-1STE1LF (bottom contact, slide lock) | Amphenol ICC | $0.3893 (5,576 in stock) | $0.3690 (3,962 in stock) | [C3168538](https://jlcpcb.com/partdetail/AmphenolICC-SFW15R1STE1LF/C3168538) | [SFW15R-1STE1LF](https://www.hqonline.com/product-detail/fpc---ffc-connectors-amphenol-sfw15r-1ste1lf-2500434032) | [amphenol-cs.com](https://www.amphenol-cs.com/product/sfw15r1ste1lf.html) | [PDF (Amphenol, SFW-R series)](https://cdn.amphenol-cs.com/media/wysiwyg/files/documentation/datasheet/flex/flexconnectors_100mm_sfw_r.pdf)³ |

All are right-angle (horizontal) SMD, 1.0 mm pitch, 15 position, for 0.3 mm
FFC.

¹ The budget connector makers have no per-part web pages: JUSHUO and HDGC only
have corporate sites, and XUNPU's site (xunpu.com) failed TLS when checked, so
the LCSC-hosted datasheets are the authoritative document links.
² HQ Online also carries a CAX-branded clone,
[AFA07-S15ECA-00-H2.5](https://www.hqonline.com/product-detail/fpc---ffc-connectors-cax-afa07-s15eca-00-h2-5-2500419281)
at $0.0642 (180 in stock).
³ The Amphenol CDN rejects non-browser clients (HTTP 403); verified in a real
browser on 2026-09-01 (HTTP 200, 504 KB `application/pdf`). The per-part
[product drawing](https://cdn.amphenol-cs.com/media/wysiwyg/files/drawing/10172241.pdf)
(same caveat) is linked from the product page's Documentation section.

## Near misses (JLCPCB only, not stocked by HQ Online)

| Product ID | Manufacturer | JLCPCB unit @100 | Notes |
|---|---|---|---|
| [SFW15R-2STE1LF](https://jlcpcb.com/partdetail/AmphenolICC-SFW15R2STE1LF/C3167933) | Amphenol ICC | $0.8385 (only 44 in stock) | Top contact, slide lock — the exact part used on Raspberry Pi boards, and the reason a Pi camera cable is opposite-side |
| [HC-FPC-1.0-15P-FHH20](https://jlcpcb.com/partdetail/HongCheng-HC_FPC_1_0_15PFHH20/C49166884) | Hong Cheng | $0.1647 (1,401 in stock) | Dual contact, flip lock — accepts the cable either way up |
| [HC-FPC-1.0-15P-CXH25](https://jlcpcb.com/partdetail/HongCheng-HC_FPC_1_0_15PCXH25/C49166850) | Hong Cheng | $0.0777 (1,103 in stock) | Bottom contact, slide lock — cheapest 15P option on JLCPCB |
| [1.0K-GT-15PB](https://jlcpcb.com/partdetail/HDGC-1_0K_GT15PB/C2915527) | HDGC | $0.1228 (2,998 in stock) | Vertical-entry slide lock, like the Pi's own connector orientation |
| [HC-FPC-1.0-15P-LH25](https://jlcpcb.com/partdetail/HongCheng-HC_FPC_1_0_15PLH25/C49166919) | Hong Cheng | $0.1155 (607 in stock) | Vertical-entry slide lock |

## Recommendation

**AFA07-S15FCA-00 / AFA07-S15ECA-00** (~$0.09–0.11, deep stock on both
services) are the pragmatic choice — pick the F (bottom) or E (top) contact
variant once the board's mounting orientation is decided. If you want the
name-brand part with the highest mating-cycle spec and the same footprint as
the Pi ecosystem, **SFW15R-1STE1LF** costs ~4× more but is also comfortably
stocked on both services.

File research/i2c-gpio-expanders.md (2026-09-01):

# I2C GPIO expanders with LED driving capability

Availability on both [JLCPCB's PCBA parts library](https://jlcpcb.com/parts) and
[NextPCB's Rev0 service](https://www.nextpcb.com/rev0-pcba) (which sources
components from [HQ Online](https://www.hqonline.com/)'s in-stock inventory).

Data collected 2026-09-01 with [`tools/partsearch.py`](tools/partsearch.py);
raw output in [`data/i2c-gpio-expanders.jsonl`](data/i2c-gpio-expanders.jsonl).
Prices are the **unit price at a quantity of 100** in USD (multiply by 100 for
the cost of 100 units).

## Available on both services

| Product ID | Manufacturer | JLCPCB unit @100 | NextPCB unit @100 | JLCPCB | NextPCB (HQ Online) | Manufacturer page | Datasheet |
|---|---|---|---|---|---|---|---|
| AW9523BTQR | Awinic | $0.2659 (59,674 in stock) | $0.2482 (5,584 in stock) | [C148077](https://jlcpcb.com/partdetail/159410-AW9523BTQR/C148077) | [AW9523BTQR](https://www.hqonline.com/product-detail/i-o-expanders-awinic-aw9523btqr-2500442592) | [awinic.com](https://www.awinic.com/en/productDetail/AW9523BTQR) | [PDF (LCSC)](https://wmsc.lcsc.com/wmsc/upload/file/pdf/v2/lcsc/1809192237_AWINIC-Shanghai-Awinic-Tech-AW9523BTQR_C148077.pdf) |
| CH423S | WCH | $0.3084 (2,528 in stock) | $0.2907 (267 in stock) | [C111663](https://jlcpcb.com/partdetail/WCH_Jiangsu_Qin_Heng-CH423S/C111663) | [CH423S](https://www.hqonline.com/product-detail/i-o-expanders-wch-ch423s-2500352610) | [wch-ic.com](https://www.wch-ic.com/products/CH423.html) | [PDF (WCH)](https://www.wch-ic.com/downloads/CH423DS1_PDF.html) |
| PCA9685PW,118 | NXP | $1.9625 (888 in stock) | $1.8418 (only 7 in stock) | [C2678753](https://jlcpcb.com/partdetail/NXPSemicon-PCA9685PW118/C2678753) | [PCA9685PW,118](https://www.hqonline.com/product-detail/led-lighting-drivers-nxp-pca9685pw-118-2500218737) | [nxp.com](https://www.nxp.com/products/power-drivers/lighting-driver-and-controller-ics/led-drivers/16-channel-12-bit-pwm-fm-plus-ic-bus-led-driver:PCA9685)¹ | [PDF (NXP)](https://www.nxp.com/docs/en/data-sheet/PCA9685.pdf)¹ |

¹ nxp.com serves HTTP 404 to non-browser clients; both links verified in a
real browser on 2026-09-01 (page loads with HTTP 200, and the datasheet URL
serves a 408 KB `application/pdf`).

Capability summary:

* **AW9523BTQR** — 16 GPIO, every pin selectable between GPIO mode and a
  256-step current-dimmed LED mode (up to 37 mA sink per pin), interrupt
  output, 4 I2C addresses, TQFN-24 (4×4 mm). The classic "GPIO expander that
  is also an LED driver".
* **CH423S** — 8 bidirectional GPIO + 16 open-drain outputs designed for LED
  segment/matrix scan driving, SOP-28. No per-pin PWM/current control.
* **PCA9685PW** — 16 channels of 12-bit PWM intended for LED control (25 mA
  sink per output); it is an LED controller rather than a true GPIO expander
  (outputs only). Note HQ Online only had 7 pieces in stock.

## Near misses (JLCPCB only, not stocked by HQ Online)

| Product ID | Manufacturer | JLCPCB unit @100 | Notes |
|---|---|---|---|
| [AW9110BTQR](https://jlcpcb.com/partdetail/247625-AW9110BTQR/C252443) | Awinic | $0.2936 (0 in stock) | 10-pin version of AW9523B |
| [AW9106BTQR](https://jlcpcb.com/partdetail/247630-AW9106BTQR/C252448) | Awinic | $0.2498 (0 in stock) | 6-pin version of AW9523B |
| [TLC59108IPWR](https://jlcpcb.com/partdetail/TexasInstruments-TLC59108IPWR/C130031) | Texas Instruments | $1.2440 (1,708 in stock) | 8-ch 8-bit PWM LED driver |
| [PCA9632DP1,118](https://jlcpcb.com/partdetail/NXPSemicon-PCA9632DP1118/C2802665) | NXP | $1.6543 (only 15 in stock) | 4-ch PWM LED driver |
| [PCA9955BTWJ](https://jlcpcb.com/partdetail/NXPSemicon-PCA9955BTWJ/C2678563) | NXP | $1.9381 (138 in stock) | 16-ch constant-current LED driver |

## Recommendation

**AW9523BTQR** is the clear winner for this project: deep stock on both
services, ~$0.25–0.27 at 100 pieces, and its LED mode does exactly the
"expander that drives LEDs" job — 16 pins is enough for 5 RGB LEDs with
per-channel 256-step dimming, no MCU firmware needed.

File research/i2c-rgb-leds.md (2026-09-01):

# I2C controllable RGB LEDs

Availability on both [JLCPCB's PCBA parts library](https://jlcpcb.com/parts) and
[NextPCB's Rev0 service](https://www.nextpcb.com/rev0-pcba) (which sources
components from [HQ Online](https://www.hqonline.com/)'s in-stock inventory).

Data collected 2026-09-01 with [`tools/partsearch.py`](tools/partsearch.py);
raw output in [`data/i2c-rgb-leds.jsonl`](data/i2c-rgb-leds.jsonl). Prices are
the **unit price at a quantity of 100** in USD (multiply by 100 for the cost of
100 units).

## Key finding

**Neither library stocks an RGB LED package with I2C built into the LED
itself.** The "smart RGB LED" packages both services stock (WS2812B, SK6812,
XL-1010RGBC etc.) all use single-wire or SPI-like protocols, not I2C. The
practical way to get an I2C-controlled RGB LED is an I2C RGB LED
*controller/driver IC* plus a plain RGB LED, so the parts below are I2C RGB LED
controller ICs (all have per-channel PWM intended for driving an RGB LED
directly).

## Available on both services

| Product ID | Manufacturer | JLCPCB unit @100 | NextPCB unit @100 | JLCPCB | NextPCB (HQ Online) | Manufacturer page | Datasheet |
|---|---|---|---|---|---|---|---|
| AW2023DNR | Awinic | $0.1849 (3,750 in stock) | $0.1726 (500 in stock) | [C401014](https://jlcpcb.com/partdetail/385728-AW2023DNR/C401014) | [AW2023DNR](https://www.hqonline.com/product-detail/led-lighting-drivers-awinic-aw2023dnr-2500438352) | [awinic.com](https://www.awinic.com/en/productDetail/AW2023DNR) | [PDF (LCSC)](https://wmsc.lcsc.com/wmsc/upload/file/pdf/v2/lcsc/2004081212_AWINIC-Shanghai-Awinic-Tech-AW2023DNR_C401014.pdf) |
| LP5562TMX/NOPB | Texas Instruments | $0.3958 (1,817 in stock) | $2.8697 (20 in stock) | [C544465](https://jlcpcb.com/partdetail/TexasInstruments-LP5562TMXNOPB/C544465) | [LP5562TMX/NOPB](https://www.hqonline.com/product-detail/led-lighting-drivers-ti-lp5562tmx-nopb-1017504026) | [ti.com](https://www.ti.com/product/LP5562) | [PDF (TI)](https://www.ti.com/lit/ds/symlink/lp5562.pdf) |
| LP5009RUKR | Texas Instruments | $0.4623 (2,568 in stock) | $0.4382 (100 in stock) | [C701960](https://jlcpcb.com/partdetail/TexasInstruments-LP5009RUKR/C701960) | [LP5009RUKR](https://www.hqonline.com/product-detail/led-lighting-drivers-ti-lp5009rukr-2500432488) | [ti.com](https://www.ti.com/product/LP5009) | [PDF (TI)](https://www.ti.com/lit/ds/symlink/lp5009.pdf) |
| IS31FL3199-QFLS2-TR | Lumissil (ISSI) | $0.5807 (1,125 in stock) | $0.6807 (292 in stock) | [C150408](https://jlcpcb.com/partdetail/161746-IS31FL3199_QFLS2TR/C150408) | [IS31FL3199-QFLS2-TR](https://www.hqonline.com/product-detail/led-lighting-drivers-issi-is31fl3199-qfls2-tr-2500412294) | [lumissil.com](https://www.lumissil.com/productsdetail/IS31FL3199.html) | [PDF (Lumissil)](https://www.lumissil.com/assets/pdf/core/IS31FL3199_DS.pdf) |
| LP5024RSMR | Texas Instruments | $0.9358 (6,748 in stock) | $0.8871 (50 in stock) | [C427525](https://jlcpcb.com/partdetail/TexasInstruments-LP5024RSMR/C427525) | [LP5024RSMR](https://www.hqonline.com/product-detail/led-lighting-drivers-ti-lp5024rsmr-2500440883) | [ti.com](https://www.ti.com/product/LP5024) | [PDF (TI)](https://www.ti.com/lit/ds/symlink/lp5024.pdf) |

Channel counts: AW2023 and LP5562 drive 3 channels (LP5562 has 4, RGB+W);
LP5009 drives 9, IS31FL3199 drives 9, LP5024 drives 24 — i.e. 3, 3 and 8 RGB
LEDs respectively.

## Near misses (JLCPCB only, not stocked by HQ Online)

| Product ID | Manufacturer | JLCPCB unit @100 | Notes |
|---|---|---|---|
| [AW2013DNR](https://jlcpcb.com/partdetail/247622-AW2013DNR/C252440) | Awinic | $0.1557 (6,907 in stock) | 3-ch, predecessor of AW2023 |
| [BCT3253EGG-TR](https://jlcpcb.com/partdetail/BROADCHIP-BCT3253EGGTR/C2961994) | Broadchip | $0.0855 (2,385 in stock) | 3-ch, cheapest option; WLCSP-12 package is hard to hand-rework |
| [IS31FL3193-DLS2-TR](https://jlcpcb.com/partdetail/2745272-IS31FL3193_DLS2TR/C2653363) | Lumissil (ISSI) | $0.5271 (6,112 in stock) | 3-ch |
| [KTD2026EWE-TR](https://jlcpcb.com/partdetail/KINETIC-KTD2026EWETR/C500368) | Kinetic | $0.4071 (only 9 in stock) | 3-ch |
| [NCP5623CMUTBG](https://jlcpcb.com/partdetail/onsemi-NCP5623CMUTBG/C892560) | onsemi | $0.3487 (0 in stock) | 3-ch with charge pump |
| [SGM31324YUDW8G/TR](https://jlcpcb.com/partdetail/SGMICRO-SGM31324YUDW8GTR/C699917) | SGMicro | $0.1833 (0 in stock) | 3-ch |

## Recommendation

**AW2023DNR** is the standout: cheapest of the parts on both services, healthy
stock on both, 3 independent 25 mA current-sink channels with autonomous
breathing/pattern engines, I2C up to 400 kHz, 2.5–5.5 V supply. Its caveat is
the DFN-10-EP (2×2 mm) package. If more LEDs are wanted later, LP5009 (3× RGB)
or LP5024 (8× RGB) scale up while staying available on both services.

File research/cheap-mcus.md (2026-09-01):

# Cheap MCUs (< $0.50) with I2C and no external parts required

Availability on both [JLCPCB's PCBA parts library](https://jlcpcb.com/parts) and
[NextPCB's Rev0 service](https://www.nextpcb.com/rev0-pcba) (which sources
components from [HQ Online](https://www.hqonline.com/)'s in-stock inventory).

Requirements applied: unit price under $0.50 at 100 pieces on **both**
services, internal flash, internal RC oscillator, internal power-on reset
(i.e. runs with nothing but supply decoupling), and a hardware I2C peripheral.

Data collected 2026-09-01 with [`tools/partsearch.py`](tools/partsearch.py);
raw output in [`data/cheap-mcus.jsonl`](data/cheap-mcus.jsonl). Prices are the
**unit price at a quantity of 100** in USD (multiply by 100 for the cost of
100 units).

## Available on both services

| Product ID | Manufacturer | JLCPCB unit @100 | NextPCB unit @100 | JLCPCB | NextPCB (HQ Online) | Manufacturer page | Datasheet |
|---|---|---|---|---|---|---|---|
| PY32F002AW15U6TR (QFN-16) | Puya | $0.1606 (34,614 in stock) | $0.1499 (400 in stock) | [C5291740](https://jlcpcb.com/partdetail/PUYA-PY32F002AW15U6TR/C5291740) | [PY32F002AW15U6TR](https://www.hqonline.com/product-detail/8-bit-mcu-microcontrollers-puya-py32f002aw15u6tr-2500438827) | [py32.org](https://py32.org/en/mcu/PY32F002Axx)¹ | [PDF (LCSC)](https://wmsc.lcsc.com/wmsc/upload/file/pdf/v2/lcsc/2303271200_PUYA--PY32F002AW15U6TR_C5291740.pdf) |
| CH32V003J4M6 (SOP-8) | WCH | $0.1845 (29,690 in stock) | $0.1722 (858 in stock) | [C5346354](https://jlcpcb.com/partdetail/WCH_Jiangsu_Qin_Heng-CH32V003J4M6/C5346354) | [CH32V003J4M6](https://www.hqonline.com/product-detail/32-bit-mcu-microcontrollers-wch-ch32v003j4m6-2500409955) | [wch-ic.com](https://www.wch-ic.com/products/CH32V003.html) | [PDF (WCH)](https://www.wch-ic.com/downloads/CH32V003DS0_PDF.html) |
| STC8G1K08-36I-SOP8 | STC Micro | $0.1966 (3,585 in stock) | $0.1835 (577 in stock) | [C713818](https://jlcpcb.com/partdetail/STCMicro-STC8G1K08_36ISOP8/C713818)² | [STC8G1K08-36I-SOP8](https://www.hqonline.com/product-detail/32-bit-mcu-microcontrollers-stc-stc8g1k08-36i-sop8-2500336185) | [stcmicro.com](https://www.stcmicro.com/stc/stc8g1k08.html) | [PDF (STC, STC8G family)](https://www.stcmicro.com/datasheet/STC8G-en.pdf) |
| CH32V003A4M6 (SOP-16) | WCH | $0.2151 (2,117 in stock) | $0.2008 (100 in stock) | [C5346357](https://jlcpcb.com/partdetail/WCH_Jiangsu_Qin_Heng-CH32V003A4M6/C5346357) | [CH32V003A4M6](https://www.hqonline.com/product-detail/32-bit-mcu-microcontrollers-wch-ch32v003a4m6-2500439164) | [wch-ic.com](https://www.wch-ic.com/products/CH32V003.html) | [PDF (WCH)](https://www.wch-ic.com/downloads/CH32V003DS0_PDF.html) |
| CH32V006F8U7 (QFN-20) | WCH | $0.2174 (2,915 in stock) | $0.1957 (1,950 in stock) | [C55112440](https://jlcpcb.com/partdetail/WCH_Jiangsu_Qin_Heng-CH32V006F8U7/C55112440) | [CH32V006F8U7](https://www.hqonline.com/product-detail/32-bit-mcu-microcontrollers-wch-ch32v006f8u7-1046732864) | [wch-ic.com](https://www.wch-ic.com/products/CH32V006.html) | [PDF (WCH)](https://www.wch-ic.com/downloads/CH32V006DS0_PDF.html) |
| CH32V003F4P6 (TSSOP-20) | WCH | $0.2237 (12,635 in stock) | $0.2088 (3,951 in stock) | [C5187096](https://jlcpcb.com/partdetail/WCH_Jiangsu_Qin_Heng-CH32V003F4P6/C5187096) | [CH32V003F4P6](https://www.hqonline.com/product-detail/32-bit-mcu-microcontrollers-wch-ch32v003f4p6-2500421881) | [wch-ic.com](https://www.wch-ic.com/products/CH32V003.html) | [PDF (WCH)](https://www.wch-ic.com/downloads/CH32V003DS0_PDF.html) |
| PY32F030K28T6 (LQFP-32) | Puya | $0.4185 (1,391 in stock) | $0.3947 (100 in stock) | [C3018720](https://jlcpcb.com/partdetail/PUYA-PY32F030K28T6/C3018720) | [PY32F030K28T6](https://www.hqonline.com/product-detail/8-bit-mcu-microcontrollers-puya-py32f030k28t6-2500438830) | [puyasemi.com](https://www.puyasemi.com/en/py32f030.html) | [PDF (LCSC)](https://wmsc.lcsc.com/wmsc/upload/file/pdf/v2/lcsc/2205171716_PUYA--PY32F030K28T6_C3018720.pdf) |

¹ Puya's own English site no longer lists the PY32F002A series (checked
2026-09-01: it does not appear in the PY32-series navigation at
[puyasemi.com/en/py32_series.html](https://www.puyasemi.com/en/py32_series.html));
[py32.org](https://py32.org/en/mcu/PY32F002Axx) (OpenPuya) is the best
persistent documentation page.

² JLCPCB stocks this MPN twice; [C18208924](https://jlcpcb.com/partdetail/STCMicro-STC8G1K08_36ISOP8/C18208924)
is $0.1893 with 30,889 in stock. The A-variant
[STC8G1K08A-36I-SOP8, C915663](https://jlcpcb.com/partdetail/STCMicro-STC8G1K08A_36ISOP8/C915663)
($0.2136, 96,225 in stock) is JLCPCB-only.

Family notes:

* **CH32V003** (RISC-V RV32EC, 48 MHz, 16 KB flash / 2 KB RAM, internal 24 MHz
  RC, 1× I2C) — the same die in SOP-8 / SOP-16 / TSSOP-20 / QFN-20; the QFN-20
  ([C5299908](https://jlcpcb.com/partdetail/WCH_Jiangsu_Qin_Heng-CH32V003F4U6/C5299908),
  $0.2527, 5,000 in stock) was not found on HQ Online. Programmed via WCH's
  1-wire SWIO (needs a WCH-LinkE).
* **CH32V006** (RV32EmC, 48 MHz, 62 KB flash / 8 KB RAM) — newer CH32V003
  successor, also single-wire debug.
* **PY32F002A** (Cortex-M0+, 24 MHz, 20 KB flash / 3 KB RAM, internal 24 MHz
  RC, 1× I2C) — programmed via standard SWD, works with ordinary ST-Link/DAP
  probes and the community [py32.org](https://py32.org/) toolchain. HQ Online
  also stocks SOP-8 (PY32F002AL15S6TU, $0.1482) and TSSOP-20
  (PY32F002AF15P6TU, $0.1544) variants, but JLCPCB had those package variants
  at 0 stock, so only the QFN-16 overlaps.
* **STC8G1K08** (1T 8051, up to 36 MHz internal RC, 8 KB flash, hardware I2C)
  — programmed over UART with a bootloader, no probe needed at all.
* **PY32F030** (Cortex-M0+, 48 MHz, 64 KB flash / 8 KB RAM) — the "big"
  option, still under $0.50 on both.

All of the above run from their internal oscillator with internal POR and
BOR — the only external parts required are supply decoupling capacitors.

## Recommendation

For an I2C peripheral device on a camera LED board, **CH32V003J4M6** (SOP-8)
or **PY32F002AW15U6TR** (QFN-16) are the sweet spot at ~$0.15–0.21 on both
services with five-digit JLCPCB stock. Choose PY32F002A if standard SWD
programming matters; choose CH32V003 for the larger community (ch32fun etc.)
and easier-to-solder SOP-8. Note the CH32V003's I2C slave mode is
well-supported in ch32fun examples.

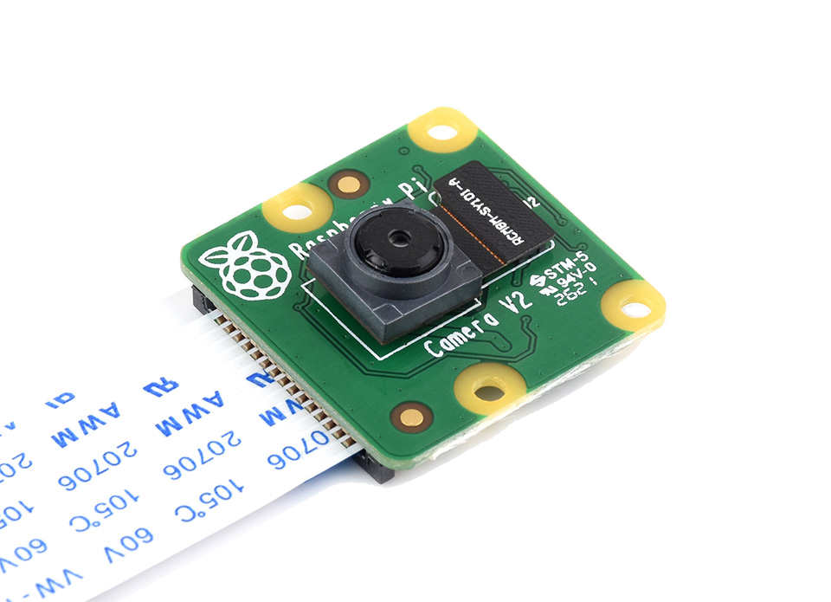
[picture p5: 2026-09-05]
docs/img/photo-camera-v2.png

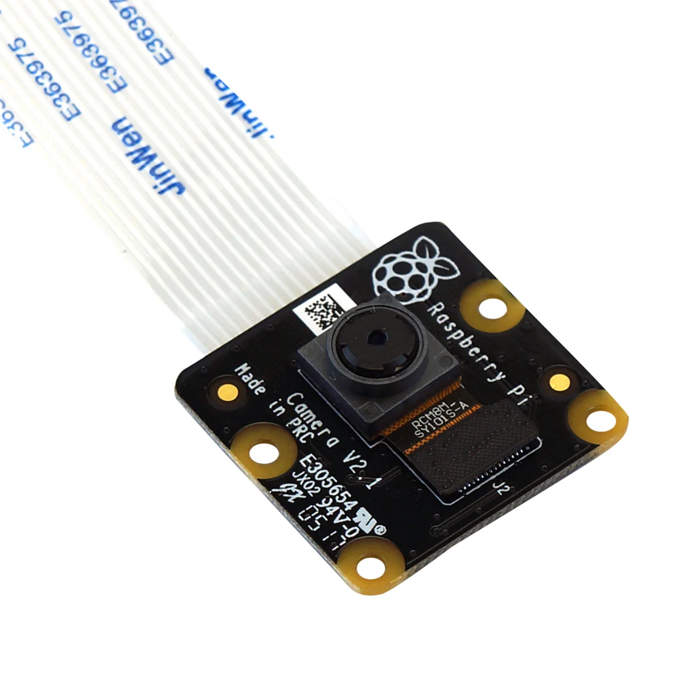
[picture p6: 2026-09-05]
docs/img/photo-camera-v2-noir.png

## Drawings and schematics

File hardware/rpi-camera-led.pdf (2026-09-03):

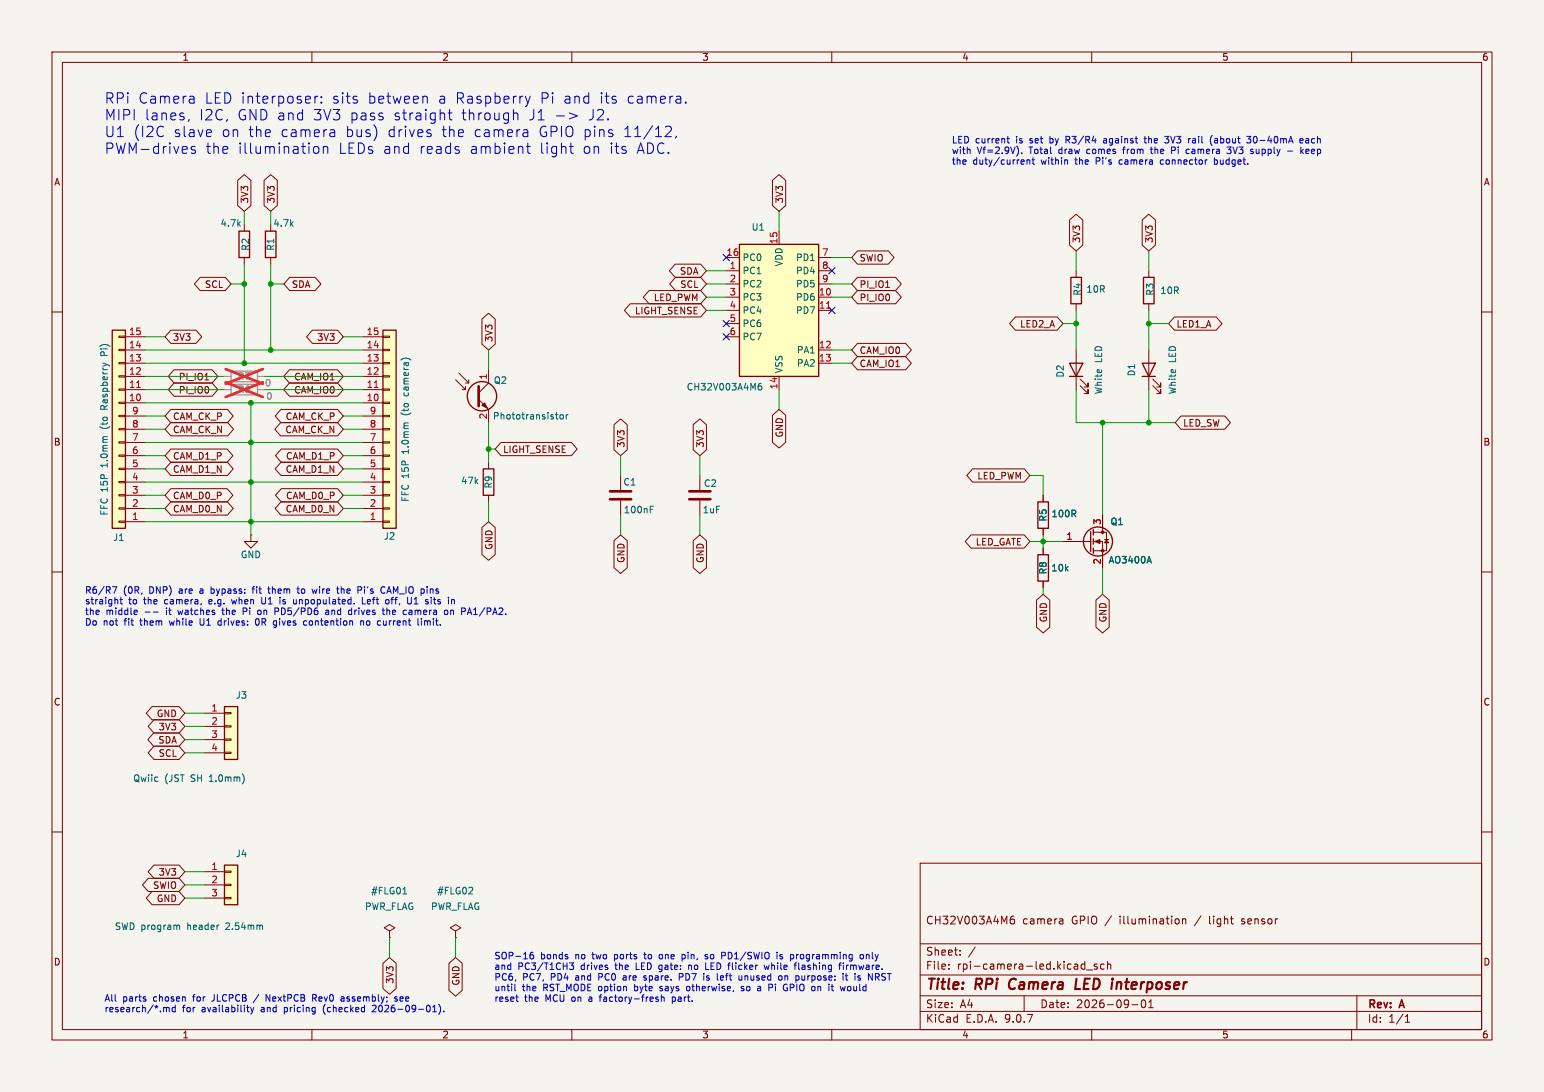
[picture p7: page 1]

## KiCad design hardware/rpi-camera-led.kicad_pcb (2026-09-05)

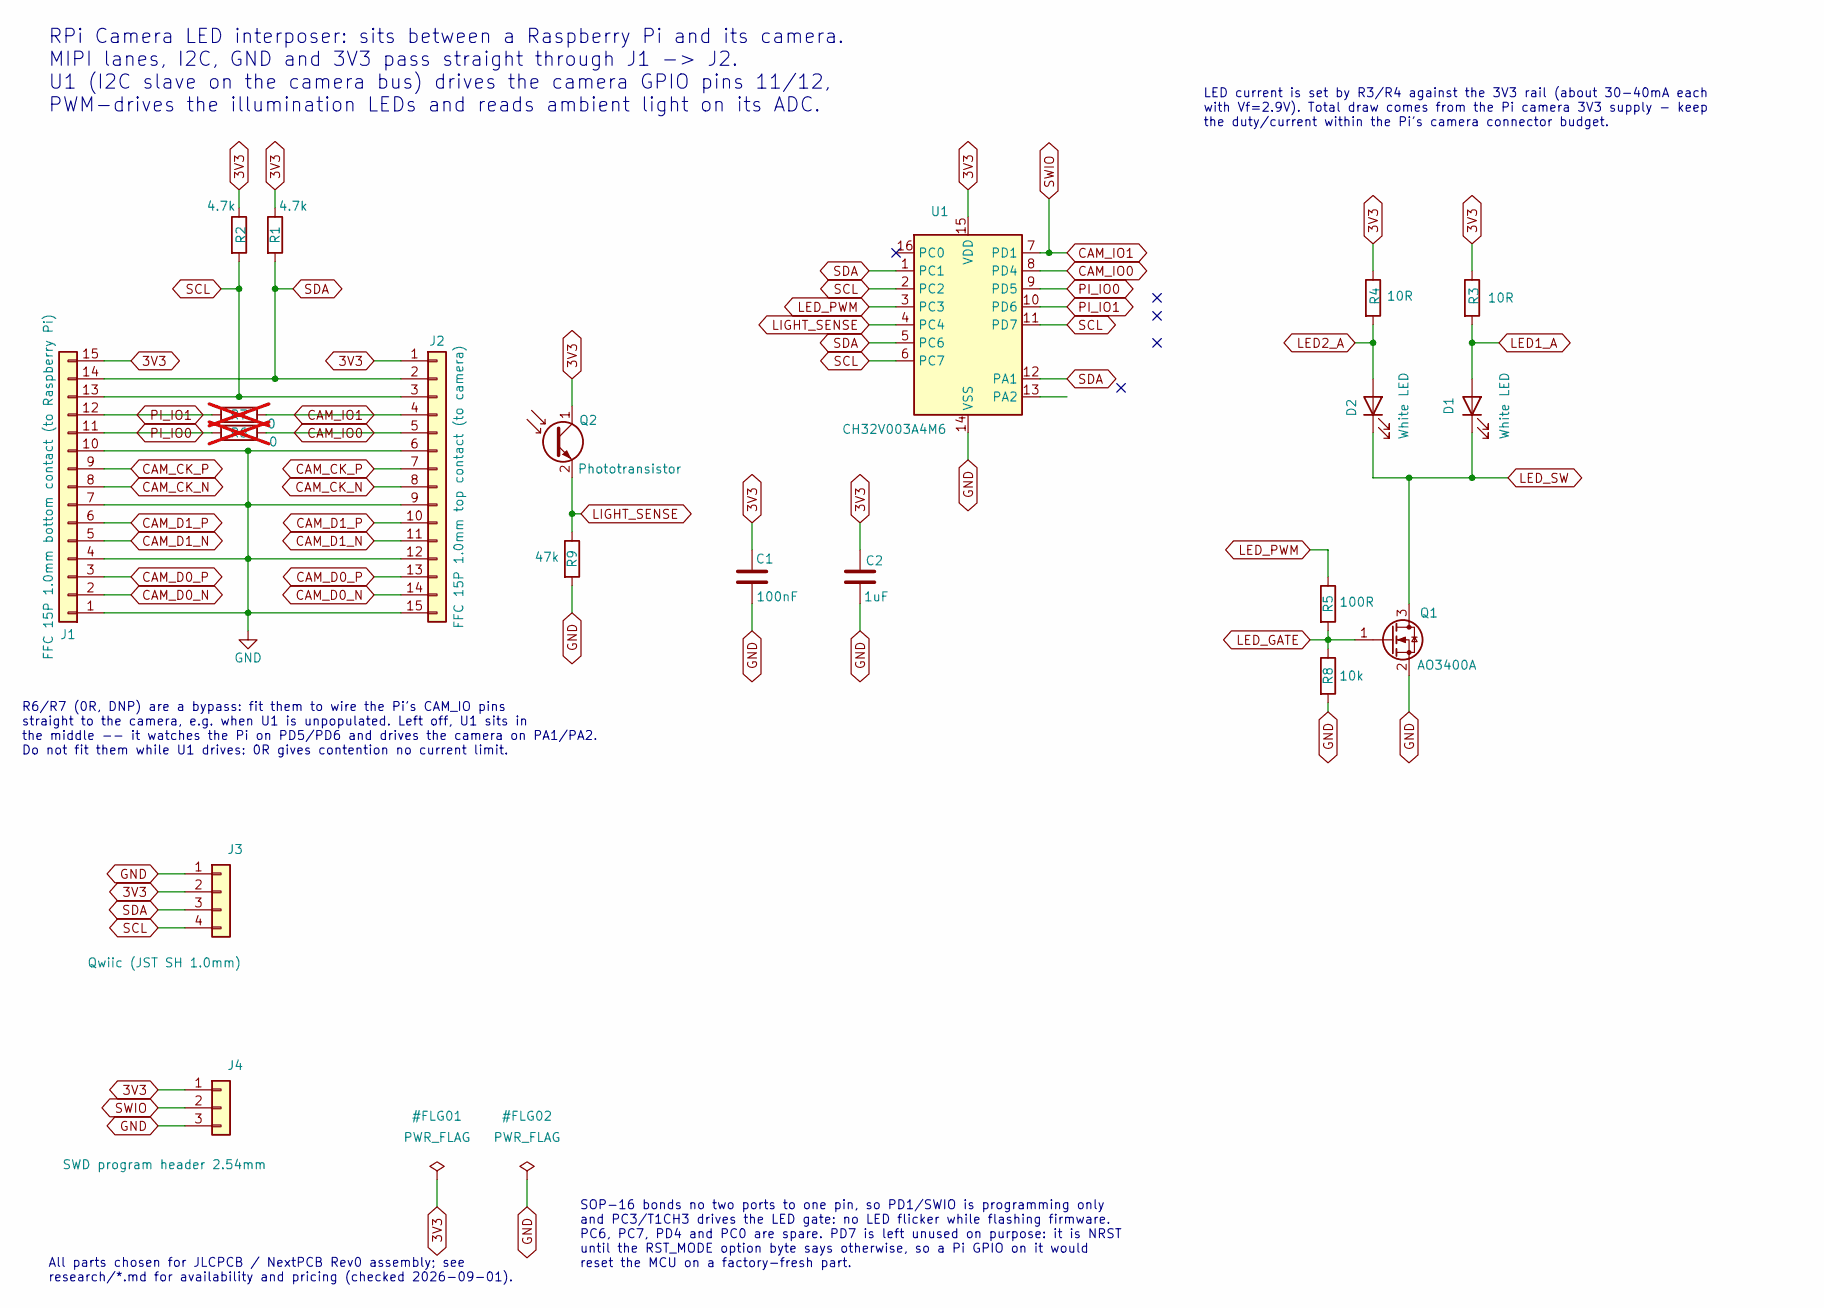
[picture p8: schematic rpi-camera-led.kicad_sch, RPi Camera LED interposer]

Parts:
C1: 100nF; C_0402_1005Metric
C2: 1uF; C_0402_1005Metric
D1, D2: White LED; LED_0805_2012Metric; MPN White 0805/2835, e.g. Hongli/NationStar
J1: FFC 15P 1.0mm bottom contact (to Raspberry Pi); JUSHUO_AFA07-S15FCA-00_1x15-1MP_P1.0mm_Horizontal; MPN JUSHUO AFA07-S15FCA-00 (LCSC C262721) /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
J2: FFC 15P 1.0mm top contact (to camera); JUSHUO_AFA07-S15ECA-00_1x15-1MP_P1.0mm_Horizontal; MPN JUSHUO AFA07-S15ECA-00 (LCSC C262742) /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
J3: Qwiic (JST SH 1.0mm); JST_SH_SM04B-SRSS-TB_1x04-1MP_P1.00mm_Horizontal; MPN JST SM04B-SRSS-TB or SH1.0-4P clone
J4: SWD program header 2.54mm; PinHeader_1x03_P2.54mm_Vertical
Q1: AO3400A; SOT-23
Q2: Phototransistor; LED_0805_2012Metric; MPN e.g. Everlight PT17-21C/L41/TR8
R1, R2: 4.7k; R_0402_1005Metric
R3, R4: 10R; R_0603_1608Metric
R5: 100R; R_0402_1005Metric
R6, R7: 0; R_0402_1005Metric; not fitted
R8: 10k; R_0402_1005Metric
R9: 47k; R_0402_1005Metric
U1: CH32V003A4M6; SOIC-16_3.9x9.9mm_P1.27mm; MPN WCH CH32V003A4M6 (LCSC C5346357)

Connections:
3V3: C1.1, C2.1, J1.15, J2.1, J3.2, J4.1, Q2.1 (C), R1.1, R2.1, R3.1, R4.1, U1.15 (VDD)
CAM_CK_N: J1.8, J2.8
CAM_CK_P: J1.9, J2.7
CAM_D0_N: J1.2, J2.14
CAM_D0_P: J1.3, J2.13
CAM_D1_N: J1.5, J2.11
CAM_D1_P: J1.6, J2.10
CAM_IO0: J2.5, R6.2, U1.8 (PD4)
CAM_IO1: J2.4, J4.2, R7.2, U1.7 (PD1)
GND: C1.2, C2.2, J1.1, J1.4, J1.7, J1.10, J2.6, J2.9, J2.12, J2.15, J3.1, J4.3, Q1.2 (S), R8.2, R9.2, U1.14 (VSS)
LED1_A: D1.2 (A), R3.2
LED2_A: D2.2 (A), R4.2
LED_GATE: Q1.1 (G), R5.2, R8.1
LED_PWM: R5.1, U1.3 (PC3)
LED_SW: D1.1 (K), D2.1 (K), Q1.3 (D)
LIGHT_SENSE: Q2.2 (E), R9.1, U1.4 (PC4)
PI_IO0: J1.11, R6.1, U1.9 (PD5)
PI_IO1: J1.12, R7.1, U1.10 (PD6)
SCL: J1.13, J2.3, J3.4, R2.2, U1.2 (PC2), U1.6 (PC7), U1.11 (PD7)
SDA: J1.14, J2.2, J3.3, R1.2, U1.1 (PC1), U1.5 (PC6), U1.12 (PA1)

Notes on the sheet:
All parts chosen for JLCPCB / NextPCB Rev0 assembly; see research/*.md for availability and pricing (checked 2026-09-01).
RPi Camera LED interposer: sits between a Raspberry Pi and its camera. MIPI lanes, I2C, GND and 3V3 pass straight through J1 -> J2. U1 (I2C slave on the camera bus) drives the camera GPIO pins 11/12, PWM-drives the illumination LEDs and reads ambient light on its ADC.
R6/R7 (0R, DNP) are a bypass: fit them to wire the Pi's CAM_IO pins straight to the camera, e.g. when U1 is unpopulated. Left off, U1 sits in the middle -- it watches the Pi on PD5/PD6 and drives the camera on PA1/PA2. Do not fit them while U1 drives: 0R gives contention no current limit.
LED current is set by R3/R4 against the 3V3 rail (about 30-40mA each with Vf=2.9V). Total draw comes from the Pi camera 3V3 supply - keep the duty/current within the Pi's camera connector budget.
SOP-16 bonds no two ports to one pin, so PD1/SWIO is programming only and PC3/T1CH3 drives the LED gate: no LED flicker while flashing firmware. PC6, PC7, PD4 and PC0 are spare. PD7 is left unused on purpose: it is NRST until the RST_MODE option byte says otherwise, so a Pi GPIO on it would reset t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

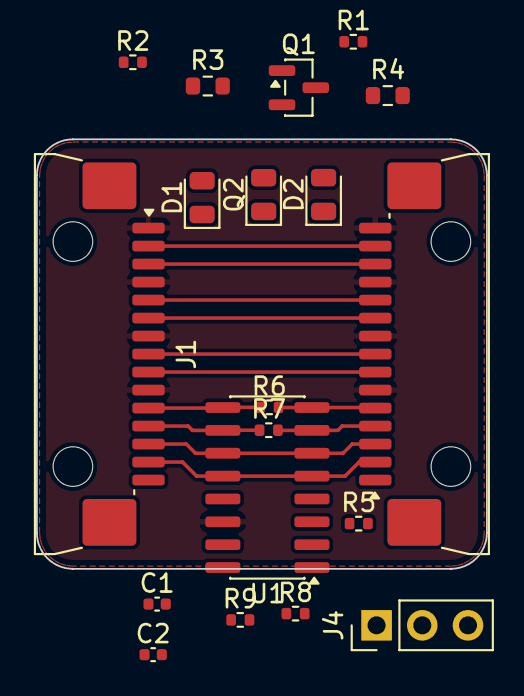
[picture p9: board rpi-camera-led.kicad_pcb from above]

Board: 2 copper layers, 25.0 x 23.9 mm, 24 parts (1 on the bottom side), 20 nets.

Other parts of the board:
H1, H2, H3, H4: MountingHole_2.2mm_M2

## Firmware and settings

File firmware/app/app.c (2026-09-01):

/*
 * CH32V003J4M6 camera-LED controller -- application.
 *
 * See firmware/README.md for the full pin map and register map. Short
 * version:
 *
 *   PD6 (bonded w/ PA1)  -> CAM_IO0, driven output or tri-state input
 *   PA2                  -> CAM_IO1, driven output or tri-state input
 *   PC1/PC2               -> I2C1 SDA/SCL (slave, address I2C_SLAVE_ADDR)
 *   PC4                   -> ADC1 channel A2, phototransistor light sensor
 *   PD1 (bonded w/ PD4,PD5) -> TIM1 CH3N hardware PWM, white LED gate
 *
 * PA1, PD4 and PD5 are the *unused* halves of pins that are bonded to
 * two ports inside the SOP-8 package (see README.md, "Hardware") and
 * are kept as floating inputs for the whole lifetime of this program
 * so they never fight the pin they're bonded to.
 */

#include "ch32fun.h"
#include <stdint.h>
#include <stdbool.h>
#include <string.h>

#include "../common/layout.h"
#include "../common/regmap_app.h"
#include "../common/i2c_slave.h"

/* Same cross-reset handshake word as the bootloader -- see
 * bootloader/bootloader.c and app.ld's .noinit section. */
volatile uint32_t noinit_boot_flag __attribute__((section(".noinit")));

static volatile uint8_t regs[REG_APP_SIZE];
static volatile bool boot_requested = false;

/* ---------------------------------------------------------------- */
/* I2C register file glue                                            */
/* ---------------------------------------------------------------- */

static void onWrite(uint8_t reg, uint8_t length)
{
	if (reg <= REG_BOOT && (uint16_t)reg + length > REG_BOOT) {
		if (regs[REG_BOOT] == REG_BOOT_MAGIC)
			boot_requested = true;
		regs[REG_BOOT] = 0;
	}
}

/* ---------------------------------------------------------------- */
/* GPIO passthrough / drive (CAM_IO0 = PD6, CAM_IO1 = PA2)           */
/* ---------------------------------------------------------------- */

static void update_gpio_channel(uint32_t pin, uint8_t bit)
{
	bool copy_en = regs[REG_CTRL] & bit;
	bool oe = regs[REG_GPIO_OE] & bit;
	bool out_level = regs[REG_GPIO_OUT] & bit;

	/* Copy mode always wins: force tri-state so the Pi's own GPIO
	 * state (through the 10k) reaches the camera unmodified. */
	if (copy_en || !oe) {
		funPinMode(pin, GPIO_CFGLR_IN_FLOAT);
	} else {
		/* Load OUTDR *before* enabling the output driver. OUTDR
		 * keeps whatever was last written to it (0 out of reset),
		 * so configuring the pin as a push-pull output first would
		 * drive the stale level onto the camera's GPIO for the few
		 * cycles until funDigitalWrite() caught up -- a real glitch
		 * on every 0->1 transition of GPIO_OE. Writing OUTDR while
		 * the pin is still a floating input has no effect on the
		 * pin (OUTDR only selects the pull direction in the
		 * pull-up/pull-down input modes, which this is not). */
		funDigitalWrite(pin, out_level ? FUN_HIGH : FUN_LOW);
		funPinMode(pin, GPIO_CFGLR_OUT_10Mhz_PP);
	}

	/* Live pin read: reflects the Pi's passed-through state when
	 * tri-stated (copy mode or OE=0), or the value we're driving
	 * when OE=1 and copy mode is off -- see README.md. */
	if (funDigitalRead(pin))
		regs[REG_GPIO_IN] |= bit;
	else
		regs[REG_GPIO_IN] &= ~bit;
}

/* ---------------------------------------------------------------- */
/* ADC (PC4 / ANALOG_2), continuously sampled + averaged              */
/* ---------------------------------------------------------------- */

/* SysTick does NOT run at the core clock by default: ch32fun's
 * handle_reset() writes SysTick->CTLR = 1 (HCLK/8) unless
 * FUNCONF_SYSTICK_USE_HCLK is set, in which case it writes 5 (HCLK).
 * See the "SYSTICK info" block in ch32fun.h. Derive the tick rate
 * instead of assuming it equals FUNCONF_SYSTEM_CORE_CLOCK, or the
 * sample period silently comes out 8x too long. */
#if defined(FUNCONF_SYSTICK_USE_HCLK) && FUNCONF_SYSTICK_USE_HCLK
#define SYSTICK_HZ (FUNCONF_SYSTEM_CORE_CLOCK)
#else
#define SYSTICK_HZ (FUNCONF_SYSTEM_CORE_CLOCK / 8u)
#endif

#define LIGHT_SAMPLE_HZ 100u
#define LIGHT_SAMPLE_PERIOD_TICKS (SYSTICK_HZ / LIGHT_SAMPLE_HZ)
#define LIGHT_EMA_SHIFT 3 /* averages over 2^3 = 8 samples */

static void adc_init(void)
{
	RCC->CFGR0 &= ~(0x1Fu << 11); /* ADCCLK = HCLK/2 */
	RCC->APB2PCENR |= RCC_APB2Periph_ADC1;

	RCC->APB2PRSTR |= RCC_APB2Periph_ADC1;
	RCC->APB2PRSTR &= ~RCC_APB2Periph_ADC1;

	funPinMode(PC4, GPIO_CFGLR_IN_ANALOG);

	ADC1->RSQR1 = 0;
	ADC1->RSQR2 = 0;
	ADC1->RSQR3 = ANALOG_2;

	ADC1->SAMPTR2 &= ~(ADC_SMP0 << (3 * ANALOG_2));
	ADC1->SAMPTR2 |= (uint32_t)7 << (3 * ANALOG_2); /* longest sample time */

	ADC1->CTLR2 |= ADC_ADON | ADC_EXTSEL;

	ADC1->CTLR2 |= CTLR2_RSTCAL_Set;
	while (ADC1->CTLR2 & CTLR2_RSTCAL_Set)
		;
	ADC1->CTLR2 |= CTLR2_CAL_Set;
	while (ADC1->CTLR2 & CTLR2_CAL_Set)
		;
}

static uint16_t adc_sample(void)
{
	ADC1->CTLR2 |= ADC_SWSTART;
	while (!(ADC1->STATR & ADC_EOC))
		;
	return (uint16_t)ADC1->RDATAR;
}

static void light_poll(void)
{
	static uint32_t last_tick;
	/* Accumulator held scaled by 2^LIGHT_EMA_SHIFT. Doing the average
	 * as `ema += (sample - ema) >> SHIFT` on an unscaled value instead
	 * loses the low bits of every update, so the filter stalls short
	 * of its input (a steady 1023 settles at ~1016 and full scale is
	 * never reachable). */
	static int32_t acc;
	static bool primed = false;

	uint32_t now = funSysTick32();
	if (primed && (now - last_tick) < LIGHT_SAMPLE_PERIOD_TICKS)
		return;
	last_tick = now;

	int32_t sample = adc_sample();
	if (!primed) {
		acc = sample << LIGHT_EMA_SHIFT; /* start at the first reading */
		primed = true;
	} else {
		acc += sample - (acc >> LIGHT_EMA_SHIFT);
	}

	uint16_t v = (uint16_t)(acc >> LIGHT_EMA_SHIFT);
	/* Publish both halves atomically with respect to the I2C
	 * interrupt, so a host reading LIGHT_LO..LIGHT_HI in one burst
	 * can never get the low byte of one sample and the high byte of
	 * the next. */
	__disable_irq();
	regs[REG_LIGHT_LO] = (uint8_t)(v & 0xFF);
	regs[REG_LIGHT_HI] = (uint8_t)(v >> 8);
	__enable_irq();
}

/* ---------------------------------------------------------------- */
/* LED PWM (PD1 = TIM1 CH3N, NOREMAP mapping)                        */
/* ---------------------------------------------------------------- */

/* PSC=186 (divide by 187) with ATRLR=255 (256 counts) gives
 * 48MHz / 187 / 256 =~ 1.003kHz PWM, and lets an 8-bit brightness
 * value map 1:1 onto the compare register. */
#define LED_PWM_PSC   186
#define LED_PWM_ATRLR 255

static void led_pwm_init(void)
{
	RCC->APB2PCENR |= RCC_APB2Periph_TIM1 | RCC_APB2Periph_AFIO;

	RCC->APB2PRSTR |= RCC_APB2Periph_TIM1;
	RCC->APB2PRSTR &= ~RCC_APB2Periph_TIM1;

	TIM1->CTLR1 = TIM_ARPE; /* buffer ATRLR too */
	TIM1->CTLR2 = 0;        /* OIS3N = 0: OC3N idles low when MOE = 0 */
	TIM1->PSC = LED_PWM_PSC;
	TIM1->ATRLR = LED_PWM_ATRLR;

	/* PWM mode 1 (OC3M = 110) with the compare value preloaded, so a
	 * brightness change is applied at an update event rather than
	 * mid-period. */
	TIM1->CHCTLR2 |= TIM_OC3M_2 | TIM_OC3M_1 | TIM_OC3PE;

	/*
	 * CAREFUL, THIS COMBINATION IS LOAD-BEARING. We drive the LED gate
	 * from OC3N (PD1), and the polarity of OC3N depends on whether the
	 * *positive* channel OC3 is enabled as well:
	 *
	 *   CC3E=0, CC3NE=1  ->  OC3N =    OC3REF ^ CC3NP
	 *   CC3E=1, CC3NE=1  ->  OC3N = (!(OC3REF)) ^ CC3NP   (complementary)
	 *
	 * With CC3E and CC3NP both set, OC3N = !(!OC3REF) = OC3REF, i.e.
	 * active high: CH3CVR = 0 keeps OC3REF low for the whole period,
	 * so brightness 0 is genuinely off. Dropping CC3E (PC3 is not
	 * bonded out on the SOP-8 package, so it looks redundant) or
	 * dropping CC3NP would invert the output and turn brightness 0
	 * into full brightness. The dead-time generator is left at 0, so
	 * OC3 and OC3N are exact complements.
	 */
	TIM1->CCER |= TIM_CC3E | TIM_CC3P | TIM_CC3NE | TIM_CC3NP;

	TIM1->CH3CVR = 0;
	TIM1->SWEVGR |= TIM_UG; /* load PSC/ATRLR/CH3CVR preloads */

	TIM1->BDTR |= TIM_MOE;
	TIM1->CTLR1 |= TIM_CEN;

	/*
	 * Only now hand PD1 to the timer. The NOREMAP mapping already puts
	 * T1CH3N on PD1 -- no AFIO remap needed (see the
	 * tim1_pwm_complementary_outputs example in the ch32v003fun
	 * submodule for the full remap table). Doing this last means the
	 * pin is never an alternate-function push-pull output while the
	 * timer is still unconfigured; until then the gate is held low by
	 * its 10k pulldown and the LEDs stay off.
	 */
	funPinMode(PD1, GPIO_CFGLR_OUT_10Mhz_AF_PP);
}

static void led_pwm_set(uint8_t brightness)
{
	/* ATRLR = 255 means the period is 256 counts, so a compare value
	 * of 255 is 255/256 = 99.6%, not fully on. Writing 256 (> ATRLR)
	 * holds OC3REF active for the entire period, which is what a
	 * brightness of 255 should mean. */
	TIM1->CH3CVR = (brightness == 255) ? 256 : brightness;
}

/* ---------------------------------------------------------------- */

int main(void)
{
	SystemInit();

	memset((void *)regs, 0, sizeof(regs));
	regs[REG_WHO_AM_I] = APP_WHO_AM_I_VALUE;
	regs[REG_FW_VERSION] = APP_FW_VERSION_VALUE;

	funGpioInitAll();

	/* Defensively (re)assert the bonded-but-unused halves of pin 1
	 * and pin 8 as floating inputs, even though this is also the
	 * post-reset default -- see the file header comment. */
	funPinMode(PA1, GPIO_CFGLR_IN_FLOAT);
	funPinMode(PD4, GPIO_CFGLR_IN_FLOAT);
	funPinMode(PD5, GPIO_CFGLR_IN_FLOAT);

	/* CAM_IO0/CAM_IO1 start tri-stated (OE defaults to 0 in regs). */

	adc_init();
	led_pwm_init();

	funPinMode(PC1, GPIO_CFGLR_OUT_10Mhz_AF_OD); /* SDA */
	funPinMode(PC2, GPIO_CFGLR_OUT_10Mhz_AF_OD); /* SCL */
	SetupI2CSlave(I2C_SLAVE_ADDR, regs, sizeof(regs), onWrite, NULL, false);

	while (1) {
		/* The I2C slave driver has a single read_only flag for the
		 * whole register file, and this file must be writable
		 * (CTRL / GPIO_OUT / GPIO_OE / LED / BOOT), so a host can
		 * write the read-only registers too. Re-stamp the constant
		 * ones every pass; GPIO_IN and LIGHT are overwritten by
		 * their own producers below. */
		regs[REG_WHO_AM_I] = APP_WHO_AM_I_VALUE;
		regs[REG_FW_VERSION] = APP_FW_VERSION_VALUE;
		regs[REG_RESERVED_07] = 0;

		update_gpio_channel(PD6, GPIO_CH0);
		update_gpio_channel(PA2, GPIO_CH1);

		light_poll();

		led_pwm_set(regs[REG_LED]);

		if (boot_requested) {
			boot_requested = false;
			noinit_boot_flag = ENTER_BOOTLOADER_RAM_MAGIC;
			PFIC->SCTLR = 1u << 31; /* system reset; bootloader runs next */
			while (1)
				;
		}
	}
}

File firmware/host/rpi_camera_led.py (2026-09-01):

#!/usr/bin/env python3
# /// script
# requires-python = ">=3.9"
# dependencies = []
# ///
"""Host-side tool for the CH32V003J4M6 camera-LED controller.

Talks to the chip over /dev/i2c-* (Linux i2c-dev, e.g. a Raspberry Pi's
I2C bus that the camera connector's I2C is wired to). No third-party
dependencies -- see i2c_raw.py, a small ctypes wrapper around the
I2C_RDWR ioctl (the same one smbus2/i2c-tools use under the hood).

Run with `uv run rpi_camera_led.py ...` (uv will use the system
Python; no packages need installing).

*** UNTESTED ON REAL HARDWARE. *** This has only been exercised
against the register maps and protocol implemented in
firmware/app/app.c and firmware/bootloader/bootloader.c by reading the
source; there is no CH32V003J4M6 board available in this environment
to verify timing, electrical behaviour, or actual I2C transaction
success/failure against silicon. Treat every command's behaviour as a
best-effort implementation of the documented protocol (firmware/README.md)
until it has been run against a real board.

Register maps mirrored (by hand -- keep in sync) from:
  firmware/common/regmap_app.h
  firmware/common/regmap_bootloader.h
  firmware/common/layout.h
"""
from __future__ import annotations

import argparse
import struct
import sys
import time
from pathlib import Path

sys.path.insert(0, str(Path(__file__).resolve().parent))
import app_trailer  # noqa: E402
from i2c_raw import I2CBus, I2CError  # noqa: E402

DEFAULT_ADDR = 0x42  # I2C_SLAVE_ADDR, layout.h

# --- application register map (regmap_app.h) --------------------------------
REG_WHO_AM_I = 0x00
REG_FW_VERSION = 0x01
REG_CTRL = 0x02
REG_GPIO_OUT = 0x03
REG_GPIO_OE = 0x04
REG_GPIO_IN = 0x05
REG_LED = 0x06
REG_LIGHT_LO = 0x08
REG_BOOT = 0x7F

APP_WHO_AM_I_VALUE = 0xC3
REG_BOOT_MAGIC = 0xB0

CTRL_COPY_EN = {0: 1 << 0, 1: 1 << 1}
GPIO_BIT = {0: 1 << 0, 1: 1 << 1}

# --- bootloader register map (regmap_bootloader.h) ---------------------------
BREG_WHO_AM_I = 0x00
BREG_BL_VERSION = 0x01
BREG_STATUS = 0x02
BREG_CMD = 0x03
BREG_PAGE_INDEX = 0x04
BREG_PAGE_CSUM_LO = 0x05
BREG_PAGE_BUF = 0x08
BREG_APP_CRC32_0 = 0x48
BREG_APP_SIZE_0 = 0x4C

BOOTLOADER_WHO_AM_I_VALUE = 0xB1

BL_STATUS_BUSY = 1 << 0
BL_STATUS_OK = 1 << 1
BL_STATUS_ERR = 1 << 2
BL_STATUS_APP_VALID = 1 << 3

BL_CMD_NONE = 0x00
BL_CMD_PROGRAM_PAGE = 0x01
BL_CMD_VERIFY_APP = 0x02
BL_CMD_RUN_APP = 0x03

FLASH_PAGE_SIZE = app_trailer.FLASH_PAGE_SIZE
APP_NUM_PAGES = app_trailer.APP_NUM_PAGES


def crc16_ccitt_false(data: bytes) -> int:
    """Must match crc16_compute() in common/crc32.h exactly."""
    crc = 0xFFFF
    for byte in data:
        crc ^= byte << 8
        for _ in range(8):
            if crc & 0x8000:
                crc = ((crc << 1) ^ 0x1021) & 0xFFFF
            else:
                crc = (crc << 1) & 0xFFFF
    return crc


class Device:
    def __init__(self, bus: I2CBus, addr: int):
        self.bus = bus
        self.addr = addr

    def read(self, reg: int, length: int) -> bytes:
        return self.bus.read_reg(self.addr, reg, length)

    def write(self, reg: int, data: bytes) -> None:
        self.bus.write_reg(self.addr, reg, data)

    def who_am_i(self) -> int:
        return self.read(REG_WHO_AM_I, 1)[0]  # same offset in both regmaps

    def mode(self) -> str:
        who = self.who_am_i()
        if who == APP_WHO_AM_I_VALUE:
            return "app"
        if who == BOOTLOADER_WHO_AM_I_VALUE:
            return "bootloader"
        return f"unknown (WHO_AM_I=0x{who:02x})"


# ------------------------------------------------------------------ app mode

def cmd_status(dev: Device, args) -> None:
    mode = dev.mode()
    print(f"mode: {mode}")
    if mode == "app":
        fw = dev.read(REG_FW_VERSION, 1)[0]
        ctrl = dev.read(REG_CTRL, 1)[0]
        gpio_out = dev.read(REG_GPIO_OUT, 1)[0]
        gpio_oe = dev.read(REG_GPIO_OE, 1)[0]
        gpio_in = dev.read(REG_GPIO_IN, 1)[0]
        led = dev.read(REG_LED, 1)[0]
        light = struct.unpack("<H", dev.read(REG_LIGHT_LO, 2))[0]
        print(f"  fw_version : {fw}")
        for ch in (0, 1):
            print(f"  ch{ch}: copy_en={bool(ctrl & CTRL_COPY_EN[ch])} "
                  f"oe={bool(gpio_oe & GPIO_BIT[ch])} "
                  f"out={bool(gpio_out & GPIO_BIT[ch])} "
                  f"in={bool(gpio_in & GPIO_BIT[ch])}")
        print(f"  led        : {led}")
        print(f"  light      : {light}")
    elif mode == "bootloader":
        _print_bootloader_status(dev)


def _print_bootloader_status(dev: Device) -> None:
    blver = dev.read(BREG_BL_VERSION, 1)[0]
    status = dev.read(BREG_STATUS, 1)[0]
    crc = struct.unpack("<L", dev.read(BREG_APP_CRC32_0, 4))[0]
    size = struct.unpack("<L", dev.read(BREG_APP_SIZE_0, 4))[0]
    print(f"  bl_version : {blver}")
    print(f"  status     : busy={bool(status & BL_STATUS_BUSY)} "
          f"ok={bool(status & BL_STATUS_OK)} err={bool(status & BL_STATUS_ERR)} "
          f"app_valid={bool(status & BL_STATUS_APP_VALID)}")
    print(f"  app crc32  : 0x{crc:08x}")
    print(f"  app size   : {size}")


def cmd_set_gpio(dev: Device, args) -> None:
    bit = GPIO_BIT[args.ch]
    reg = dev.read(REG_GPIO_OUT, 1)[0]
    reg = (reg | bit) if args.level else (reg & ~bit)
    dev.write(REG_GPIO_OUT, bytes([reg & 0xFF]))


def cmd_set_oe(dev: Device, args) -> None:
    bit = GPIO_BIT[args.ch]
    reg = dev.read(REG_GPIO_OE, 1)[0]
    reg = (reg | bit) if args.enable else (reg & ~bit)
    dev.write(REG_GPIO_OE, bytes([reg & 0xFF]))


def cmd_set_copy(dev: Device, args) -> None:
    bit = CTRL_COPY_EN[args.ch]
    reg = dev.read(REG_CTRL, 1)[0]
    reg = (reg | bit) if args.enable else (reg & ~bit)
    dev.write(REG_CTRL, bytes([reg & 0xFF]))


def cmd_set_led(dev: Device, args) -> None:
    if not 0 <= args.value <= 255:
        raise SystemExit("--value must be 0-255")
    dev.write(REG_LED, bytes([args.value]))


def cmd_get_light(dev: Device, args) -> None:
    light = struct.unpack("<H", dev.read(REG_LIGHT_LO, 2))[0]
    print(light)


def cmd_get_gpio(dev: Device, args) -> None:
    gpio_in = dev.read(REG_GPIO_IN, 1)[0]
    print(f"ch0={bool(gpio_in & GPIO_BIT[0])} ch1={bool(gpio_in & GPIO_BIT[1])}")


# --------------------------------------------------------------- bootloader

def _wait_for_mode(dev: Device, want: str, timeout_s: float = 2.0) -> None:
    deadline = time.monotonic() + timeout_s
    last_exc = None
    while time.monotonic() < deadline:
        try:
            if dev.mode() == want:
                return
        except I2CError as e:
            last_exc = e
        time.sleep(0.02)
    extra = f" (last error: {last_exc})" if last_exc else ""
    raise SystemExit(f"timed out waiting for device to reach mode={want}{extra}")
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

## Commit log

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2026-09-01 Capture raw JLCPCB/HQ Online availability data for all four part categories
    Also fix partsearch crash when a JLCPCB keyword search returns no results.
    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
    [partsearch.py]
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2026-09-01 Add schematic generator and ERC/netlist verifier for the interposer
    gen_schematic.py builds the KiCad 9 schematic from the installed
    symbol libraries (symbols embedded, connections via wire stubs plus
    global labels, placements snapped to the 1.27mm grid).
    check_schematic.py runs kicad-cli ERC and compares the exported
    netlist pin-by-pin against the design intent.
    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
    [check_schematic.py, gen_schematic.py]
2026-09-01 Add RPi camera interposer schematic (CH32V003 GPIO/LED/light sensor)
    Two 15-pin 1.0mm FFC connectors pass the MIPI lanes, I2C, GND and 3V3
    straight through. A CH32V003J4M6 (I2C slave on the camera bus) drives
    the camera CAM_IO0/1 pins, PWM-drives two white illumination LEDs via
    an AO3400A low-side switch, and reads a phototransistor on its ADC
    (PC4/A2). I2C is broken out to a Qwiic JST-SH header, SWIO/3V3/GND to
    a 2.54mm programming header, and DNP 0R jumpers restore the Pi's own
    CAM_IO pass-through when U1 is unpopulated.
    Pinouts verified against the WCH CH32V003 datasheet (SOP8 bonding:
    pin1=PD6/PA1, 3=PA2, 5=PC1/SDA, 6=PC2/SCL, 7=PC4/A2, 8=PD1/SWIO+
    PD4/PD5) and the 15-pin camera FFC pin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
    [rpi-camera-led.kicad_sch]
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2026-09-01 Add the fail-safe I2C bootloader
    - Vendors ch32v003fun's MIT-licensed i2c_slave.h (register-pointer +
    auto-increment I2C slave, i2c-tools/regmap-i2c compatible) into
    common/ so bootloader and app don't depend on the submodule's
    examples/ tree.
    - Reworks crc32.h into a chainable, zlib-compatible crc32_update() so
    the app's CRC32 can be verified directly out of flash without a RAM
    copy, treating the header's own crc32 field as zero.
    - bootloader.c: always runs first (occupies flash 0x0000-0x0FFF),
    verifies the app's CRC32, and either jumps straight to a valid app
    or stays resident serving the BREG_* I2C command window (program a
    64-byte page, verify, run) from regmap_bootloader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
    [bootloader.c, i2c_slave.h]
2026-09-01 Add the application firmware
    app.c implements all six I2C-controlled functions over the
    register-pointer regmap from regmap_app.h:
    - CAM_IO0 (PD6) / CAM_IO1 (PA2) drive/tri-state + copy-mode passthrough,
    with PA1/PD4/PD5 (the bonded-but-unused halves of those package pins)
    kept as floating inputs for the program's whole lifetime.
    - Live GPIO readback (REG_GPIO_IN).
    - Continuously-sampled, exponentially-averaged illumination (PC4 /
    ADC channel A2) in REG_LIGHT.
    - 0-1003Hz-ish hardware PWM (TIM1 CH3N on PD1, NOREMAP mapping) for
    LED brightness, 0-255 mapping 1:1 onto the compare register.
    - REG_BOOT: crosses a warm reset into the bootloader via the shared
    NOINIT handshake word.
    Also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
    [app.c, app_trailer.py]
2026-09-01 Add host-side I2C tool (untested on hardware)
    rpi_camera_led.py: a dependency-free (stdlib-only, via i2c_raw.py's
    ctypes wrapper around the I2C_RDWR ioctl -- no smbus2 needed) CLI to
    read sensors, drive/tri-state/copy-mode the camera GPIOs, set LED
    brightness, and perform a full fail-safe firmware upgrade
    (enter-bootloader -> program all 192 pages with per-page CRC16 ack ->
    verify CRC32 -> run-app), reusing host/app_trailer.py for the image
    build/verify so it can never disagree with the on-device algorithm.
    Sanity-checked (not on real hardware, see README.md and the module
    docstring):
    - CRC16 implementation matches the standard CRC-16/CCITT-FALSE check
    value (0x29B1 for "123456789").
    - Th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
    [i2c_raw.py, rpi_camera_led.py]
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2026-09-01 Add 2-layer PCB with board outline, mounting holes and placement
    Creates hardware/rpi-camera-led.kicad_pcb from the schematic netlist with a
    scripted, reproducible placement (hardware/tools/gen_pcb.py, run inside the
    KiCad snap runtime via hardware/tools/run_in_kicad.sh).
    Board is the Raspberry Pi Camera Module 2 outline: 25.000 x 23.862 mm with
    2.0 mm corner radii, and 4x Ø2.2 mm NPTH mounting holes on the camera's
    21.0 x 12.5 mm pattern. The X inset matches the camera exactly (2.0 mm);
    the row pair is centred between the two FFC connectors because this board
    carries a connector on *both* 23.862 mm edges and the camera's own Y offsets
    would put the holes on the connector solder tabs.
    J1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
    [rpi-camera-led.kicad_pcb]
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2026-09-01 Fix I2C slave: spurious write callbacks and unclearable error flags
    Three defects in the vendored ch32v003fun i2c_slave.h, all of which
    matter for this firmware:
    1. The write callback fired on master *reads*. Upstream calls it from
    the STOPF branch unconditionally, and `position` has advanced past
    `offset` by then, so a read of N bytes was reported to the
    application as a register write of N bytes. The bootloader's
    "was BREG_CMD written?" test therefore re-executed whatever was
    still sitting in regs[BREG_CMD] whenever a host read a block
    spanning register 0x03 (i2cdump, or a regmap block read), and the
    app's REG_BOOT test fired on a pure read of 0x7F. The `writing`
    f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
    [i2c_slave.h]
2026-09-01 Bootloader: never trust host-writable state when jumping to the app
    BL_CMD_RUN_APP gated the jump on BL_STATUS_APP_VALID read back out of
    regs[BREG_STATUS]. That register lives in the I2C register file, which
    the slave driver makes fully host-writable (it has one read_only flag
    for the whole file, and the file must be writable for PAGE_INDEX /
    PAGE_CSUM / PAGE_BUF). A single I2C write of [0x02, 0x08, 0x03] --
    STATUS = APP_VALID followed by CMD = RUN_APP in the same transaction --
    therefore made the bootloader jump into a blank or half-programmed app
    region, which is precisely the outcome the boot-time CRC32 exists to
    prevent. On a factory-blank part that means executing 0xFFFFFFFF.
    RUN_APP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
    [bootloader.c]
2026-09-01 Bootloader: relock fast-programming mode between pages
    flash_lock() only set CR_LOCK_Set (FLASH_CTLR bit 7), leaving FLOCK
    (bit 15, fast-programming-mode lock) clear after the first page. The
    next program_page() then re-ran the FLASH->MODEKEYR key sequence on an
    already-unlocked controller. On this STM32-derived flash controller
    that is the "keys written more than once" case, which can lock
    FLASH_CTLR until reset -- so every page after the first could silently
    fail to program, and an upgrade would abort with the app region
    half-written (recoverable, thanks to the CRC32 check, but a broken
    upgrade path).
    Locking LOCK|FLOCK together also makes the existing
    `FLASH->CTLR & 0x8080` unlock guard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
    [bootloader.c]
2026-09-01 App: fix light-sensor sample rate, EMA stall, GPIO glitch and RO regs
    Four independent defects in the application:
    1. LIGHT_SAMPLE_PERIOD_TICKS assumed SysTick counts at the core clock.
    It does not: ch32fun's handle_reset() writes SysTick->CTLR = 1,
    i.e. HCLK/8 = 6MHz, unless FUNCONF_SYSTICK_USE_HCLK is set (it is
    not here). FUNCONF_SYSTEM_CORE_CLOCK/100 = 480000 ticks was
    therefore 80ms, so the ADC ran at 12.5Hz, not the 100Hz the code and
    README both claim. The rate is now derived from the SysTick
    configuration so it stays right either way.
    2. The exponential average was computed as `ema += (sample - ema) >> 3`
    on an unscaled value, which discards the low three bits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
    [app.c]
2026-09-01 App: LED brightness 255 is now fully on, and PD1 goes AF last
    - led_pwm_set() wrote the brightness straight into CH3CVR. With
    ATRLR = 255 the period is 256 counts, so 255 gave 255/256 = 99.6%
    duty and full brightness was unreachable. A compare value above
    ATRLR holds OC3REF active for the whole period, so 255 now writes
    256.
    - led_pwm_init() put PD1 into alternate-function push-pull *before*
    resetting and configuring TIM1, leaving the pin driven by an
    unconfigured peripheral for the duration. The pin is now handed to
    the timer last, after MOE and CEN; until then the MOSFET gate is
    held low by its 10k pulldown.
    - Enable OC3PE/ARPE so a brightness change lands at an update ev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
    [app.c]
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2026-09-01 Bootloader: reject a corrupt app_used_size instead of hanging on it
    verify_app() accepted any app_used_size in [APP_HEADER_SIZE, APP_SIZE]
    and handed it to compute_app_crc(), whose final chunk length is
    app_used_size - (APP_HEADER_OFFSET + 8 + 4)
    i.e. app_used_size - 12284. For anything below APP_SIZE that underflows
    to nearly 2^32, so the bootloader would bit-bang a CRC32 over ~4GiB
    starting past the end of flash. That is not a wrong answer, it is a
    hang -- at boot, on every boot, with the I2C slave not yet started and
    no watchdog to break out of it, recoverable only over SWD. A single
    half-programmed page 191 whose magic word survives while the size word
    does not is enough to trigger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
    [bootloader.c]
2026-09-01 Bootloader: sequence verify_app() before the STATUS read-modify-write
    `bl_status |= verify_app() ? BL_STATUS_OK : BL_STATUS_ERR;` reads and
    writes bl_status while calling a function that also updates it (with
    the APP_VALID result). C leaves the evaluation order of the two
    operands unspecified, so a compiler may load bl_status before the call
    and store back a value in which the APP_VALID update is lost -- the
    host would then see OK but not APP_VALID after VERIFY_APP and treat a
    perfectly good upgrade as a failure.
    gcc 14.2.0 at -Os happens to emit the load after the call, so the
    current build is correct by luck; a different optimiser or version
    need not be. Split it into a sequenced local.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
    [bootloader.c]
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2026-09-01 Route the six MIPI pass-through nets in the pcbnew GUI
    J1 and J2 face outward on opposite edges, so their contact rows are mirrored
    about the board centre and the three differential pairs have to reverse order
    between the two connectors. That reversal is done in the empty pocket under
    the J1 housing: each net leaves its pad westward on F.Cu, drops through a via
    into a B.Cu channel at its own depth (deeper for a wider span, which keeps the
    whole fan planar), runs north/south to its destination row, then crosses the
    board on B.Cu and comes back up to the matching J2 pad.
    Routed by mouse in pcbnew running on a private Xvfb display; adds
    hardware/tools/gui_route.py (xdotool driver, mm->pixel t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
    [rpi-camera-led.kicad_pcb]
2026-09-01 Wire the schematic connections directly in eeschema
    Hand edits made in the schematic editor: most of the generated
    global-label stubs are replaced by real wires and junctions between
    adjacent parts (78 -> 86 wires, 0 -> 8 junctions), so connectivity is
    visible on the sheet rather than implied by matching label names. GND
    picks up a power symbol and the remaining single labels now just name
    their nets: GND 17 -> 9 labels, LED1_A/LED2_A 2 -> 1, LED_GATE 3 -> 1,
    LIGHT_SENSE 3 -> 2.
    U1's value becomes CH32V003A4M6; its symbol and footprint still have to
    follow it to SOP-16, which is the next commit.
    Verified no connections moved: kicad-cli ERC reports only the known
    MCU_WCH_RiscV-not-in-globa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
    [rpi-camera-led.kicad_sch]
2026-09-01 Move U1 to the CH32V003A4M6 in SOP-16
    Swap the SOP-8 CH32V003JxMx symbol for KiCad's CH32V003AxMx and the
    SOIC-8 footprint for SOIC-16_3.9x9.9mm_P1.27mm, matching the value Tim
    set. Pin assignment, against WCH's CH32V003 datasheet V1.8 table 2-1
    (which tabulates SOP16 alongside the other packages):
    1 PC1 SDA 10 PD6 CAM_IO0
    2 PC2 SCL 13 PA2 CAM_IO1
    3 PC3 LED_PWM 14 VSS GND
    4 PC4 LIGHT_SENSE 15 VDD 3V3
    7 PD1 SWIO
    PC1/PC2/PC4/PD6/PA2 keep the ports they had on SOP-8, so the I2C
    peripheral, the ADC channel (A2) and the GPIO pass-through code carry
    over unchanged.
    The package earns its extra 8 pins by undoing the SOP-8 compromi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
    [rpi-camera-led.kicad_sch]
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2026-09-01 Give U1 dedicated Pi-sense and camera-drive pins
    Rework the camera GPIO section now that SOP-16 has pins to spare, and
    redraw J1/J2 as facing connector blocks so the pass-through nets read
    straight across the sheet.
    U1 no longer shares one pin per channel with the coupler. It sits
    across it instead: PD6/PD7 (pins 10/11) watch the Pi side and PA1/PA2
    (pins 12/13) drive the camera side, so reading the Pi no longer means
    tri-stating the pin that drives the camera. R6/R7 drop from 10k to 0R,
    turning them from couplers into a straight bypass link.
    Two things this leaves open, both flagged rather than guessed at:
    * PD7 (pin 11) carries the PI_IO0 label, the same net as PD6 (pin
    10), whi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
    [rpi-camera-led.kicad_sch]
2026-09-01 Mark R6/R7 do-not-populate
    The 0R links are a build option, not part of the default build: leaving
    them off is what puts U1 in the middle of each GPIO channel, watching
    the Pi on PD6/PD7 and driving the camera on PA1/PA2. Fitting one ties
    the Pi's pin straight to the camera, which is what you want when U1 is
    unpopulated and the board is just a pass-through.
    Rewrite the on-sheet note to match: it still described 10k couplers and
    an override current that no longer exists. With 0R there is nothing to
    limit contention, so the note now says not to fit them while U1 drives.
    Also drop the note clear of J1's reference designator, which it had
    grown into.
    check_schematic.py stays red on PI_IO0/CA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
    [rpi-camera-led.kicad_sch]
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2026-09-01 Sense the Pi's IO1 on PD5, and leave PD7 alone
    Pin 11 carried a second PI_IO0 label, so PD6 and PD7 sat on one net
    while PI_IO1 reached no U1 pin at all. Rather than relabel pin 11,
    move the channel-1 sense to PD5 (pin 9) and no-connect pin 11.
    PD5 is the better pin on every count. PD7 is NRST until the RST_MODE
    option byte in flash says otherwise, so a Pi GPIO wired to it would
    reset the MCU on any part that has not been provisioned yet -- a board
    that misbehaves until firmware has run once is a bad failure mode for
    something assembled in volume. PD5 has no such second life, sits next
    to PD6 so both sense pins are adjacent on port D, and mirrors the drive
    pair on PA1/PA2.
    9 PD5 P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
    [rpi-camera-led.kicad_sch]
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2026-09-01 Update the board for the top-contact J2
    Bring the PCB in step with the schematic's connector change, and repair
    damage the interrupted routing session left in the working file.
    J2's footprint becomes rpi-camera-led:JUSHUO_AFA07-S15ECA-00, and both
    connectors pick up the Value and MPN text that now names their contact
    type. Nothing else moves: the ECA and FCA land patterns are identical,
    so the swap is an identity change only. The script asserted pad count
    and pad geometry were unchanged rather than trusting that, and KiCad's
    own DRC now reports schematic_parity: 0.
    The working file also carried a duplicate J1 -- two fully net-connected
    footprints 0.01mm apart, a stray copy from the sessi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
    [rpi-camera-led.kicad_pcb]
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2026-09-01 Actually reverse J2's pin order, which a708eef only implied
    a708eef swapped J2 to the top-contact part and claimed that made the
    bus route straight. It did not. The two variants share one land
    pattern, so changing the part moved no pad and altered no net: the
    board was byte-identical in every way that matters and every
    pass-through net still had to cross the bus. Tim spotted it -- the
    connector did not seem to have changed because nothing had.
    The reversal has to live in the net mapping, and now does. Measured
    from the board rather than assumed: J1 sits at -90 degrees and J2 at
    +90, so J1 pad k is physically opposite J2 pad 16-k (J1.1 faces J2.15,
    J1.8 faces J2.8, dy 0.049mm). A net ca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
    [rpi-camera-led.kicad_pcb, rpi-camera-led.kicad_sch]
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2026-09-01 Check the connector alignment instead of measuring it by hand
    The straight bus depends on a geometric property that is easy to lose
    to a stray drag and expensive to notice: a 0.05mm slip puts a dogleg in
    all fifteen nets and nothing complains. It has already happened once.
    check_pcb.py asserts it as a number -- worst |dY| over the fifteen
    facing pairs J1.k / J2.(16-k), and that both pad columns sit the same
    distance from the board centreline -- then runs DRC and fails on any
    schematic-parity issue. Checked against the board before cd77501,
    where it reports 0.049mm misaligned and 0.625mm off-mirror, so it is
    not vacuous.
    README gains the reason the two connectors are different parts, whic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
    [check_pcb.py]
2026-09-01 Tim's KiCad session: six straight MIPI runs, J2 re-mirrored
    Committing the working files as they stand so the routing is not lost.
    This is an inconsistent intermediate state, recorded rather than
    tidied, because the two halves disagree:
    * Six straight traces on F.Cu, 0.2mm, each a full 12.6mm run at
    constant Y from J1's pad column to J2's -- the MIPI pairs and
    clock, exactly the payoff the alignment work was for.
    * J2 carries (mirror x) again, which puts the connector mapping back
    to J1.k <-> J2.k and undoes be3c223.
    Straight runs need the reversed mapping, so with the mirror back five
    of the six traces land on a pad of the wrong net: CAM_CK_P on J2.7
    (GND), CAM_D0_N on J2.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
    [rpi-camera-led.kicad_pcb, rpi-camera-led.kicad_sch]
2026-09-01 Put J2 back on the original bottom-contact part
    Undo a708eef and be3c223: J1 and J2 are the same AFA07-S15FCA-00
    again, wired pin-for-pin, so a standard same-side Raspberry Pi camera
    cable works at both ends. That was the real cost of the top-contact
    route -- it needed an opposite-side (type D) FFC or a fold on the
    camera segment, which is a poor trade for a board whose point is to sit
    transparently in an existing cable run.
    Everything that existed only to support the swap goes with it: the
    project footprint library holding the renamed ECA copy, its
    fp-lib-table, the contact-type annotations in both connectors' Value
    and MPN fields, and the on-sheet note explaining why the parts
    differed.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
    [rpi-camera-led.kicad_pcb, rpi-camera-led.kicad_sch]
2026-09-01 Tim's KiCad session: U1 pins rearranged, bus routing extended
    Committing work in progress so it is not lost. U1's assignment moves
    toward the arrangement Tim asked about -- camera GPIOs on pins 7/8, Pi
    sense on 9/10, I2C also brought out to 5/6 and 11/12 -- J2 goes back to
    the reversed pin mapping, and the board grows to 37 track segments with
    unconnected down from 49 to 35.
    It does not pass its checks yet. Recorded here rather than fixed,
    because each of these is a design decision:
    * ERC error, U1.13 (PA2) is connected to nothing, with a 0.038mm wire
    fragment left behind at the same point -- the remains of dragging
    CAM_IO1 off that pin.
    * SWIO and CAM_IO1 are the same net.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
    [rpi-camera-led.kicad_pcb, rpi-camera-led.kicad_sch]
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2026-09-03 J2 becomes the top-contact part, so both cables are standard
    With J1 and J2 both bottom-contact, the camera-side cable segment had to
    be a same-side (type 1) FFC -- not a part you can buy as a Raspberry Pi
    camera cable. Making J2 top-contact means the interposer flips which
    face of the cable carries copper, and both segments become ordinary
    opposite-side Raspberry Pi camera cables.
    The reasoning, since it is easy to get backwards:
    - the Raspberry Pi's CSI socket is top-contact (SFW15R-2STE1LF) and
    the camera module's is bottom-contact (per Gert van Loo, who
    designed the camera board), which is exactly why the standard cable
    is opposite-side -- "type 2" in JUSHUO's and Gert's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
    [rpi-camera-led.kicad_pcb, rpi-camera-led.kicad_sch]
2026-09-03 Add board renders and the script that regenerates them
    Three images for the README: raytraced 3D views from the front and back,
    and an F.Cu / B.Cu / F.SilkS / Edge.Cuts plot of the layout.
    The 3D views are zoomed to 0.45 rather than framed on the board, because
    eleven of the twenty footprints -- C1, C2, J3, J4, Q1, R1-R4, R8, R9 --
    are still parked outside the outline while the layout is in progress.
    Framing on the board would crop them out and make it look finished.
    kicad-cli does not inherit the GUI's path substitutions, so the script
    passes -D KICAD9_3DMODEL_DIR explicitly; without it every model silently
    resolves to nothing. It also reports which models could not be found,
    since KiCad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
    [render_board.py]
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2026-09-04 Build 3D models for the FFC connectors, and wire both up
    KiCad's stock footprint points at
    Connector_FFC-FPC.3dshapes/JUSHUO_AFA07-S15FCA-00_...step, which does not
    exist. Not in the snap, and not upstream either: kicad-packages3D ships
    112 files in that library and none of them are JUSHUO. Component Search
    Engine has one, but SamacSys's terms do not permit redistribution, so it
    cannot go in an Apache-2.0 repository.
    So gen_connector_model.py builds one from the manufacturer's drawing,
    which we can carry. Everything dimensioned comes from that drawing or
    from KiCad's stock footprint, whose F.Fab outline is the body outline and
    whose land pattern was already verified against the drawing p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
    [rpi-camera-led.kicad_pcb, rpi-camera-led.kicad_sch]
2026-09-04 Correct the cable direction, repour the zones, add two renders
    I had the connector back to front, and said so in the README, which was
    wrong and is now fixed. The cable enters at the LATCH end, not the
    terminal end, so both cables enter from the board's outside edges and the
    placement was right all along. Three independent readings of the
    manufacturer's drawing agree:
    - Section A-A shows the solder tail stepping down and out at one end
    while the cable channel opens at the other;
    - the top view labels "Terminal" at one end and "Latch" at the other,
    with the 5.30mm housing between them;
    - a slide lock can only work that way round -- pull the slider, insert
    the cable, push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
    [rpi-camera-led.kicad_pcb]
2026-09-04 Cable stubs now show which face carries the copper, and are labelled
    The stubs were a plain strip with a blue patch always on top, which said
    nothing about the thing that actually matters on an FFC cable: which face
    the conductors are on. Both ends looked identical, so the render could
    not show the asymmetry the whole F/E connector pairing exists to create.
    Each stub now carries bared conductors on one face and the blue backing
    on the other, at the same end, the way a real cable does -- and the two
    are built opposite ways up. J1 is the lower-contact part, so its cable
    presents copper downwards and shows its backing; J2 is upper-contact, so
    its cable is flipped and shows the conductors. I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
    [gen_connector_model.py, render_board.py]
2026-09-05 Add back the Raspberry Pi camera board's mounting holes
    The board uses the Camera Module 2 outline, so it should take the same
    screws. d0c15fe put the holes in; they were lost somewhere after that
    and nobody noticed, which is exactly the failure check_pcb.py exists to
    catch, so it now verifies the pattern too -- confirmed non-vacuous by
    running it against the previous commit's board, where it reports 0 holes
    and fails.
    Positions are from the official mechanical drawing RP-008149-DS
    (RPI-CAM-V2_1): "4x 2.2mm diameter holes", 2mm in from each end of the
    25mm axis for a 21.0mm pitch, and 2.0 and 14.5mm from one end of the
    23.862mm axis for a 12.5mm pitch. That second pair is asymmetric on th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
    [rpi-camera-led.kicad_pcb]
